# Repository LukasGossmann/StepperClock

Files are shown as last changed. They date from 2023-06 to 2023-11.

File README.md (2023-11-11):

<p align="center">
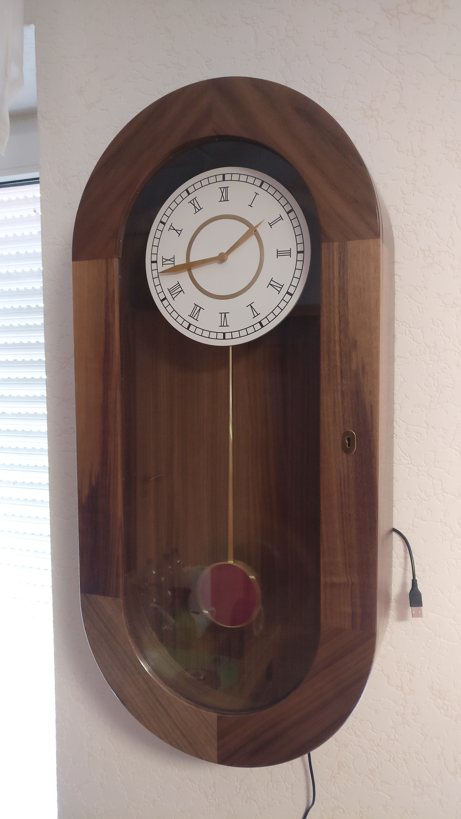
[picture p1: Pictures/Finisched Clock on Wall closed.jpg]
Front view of the clock with the door closed

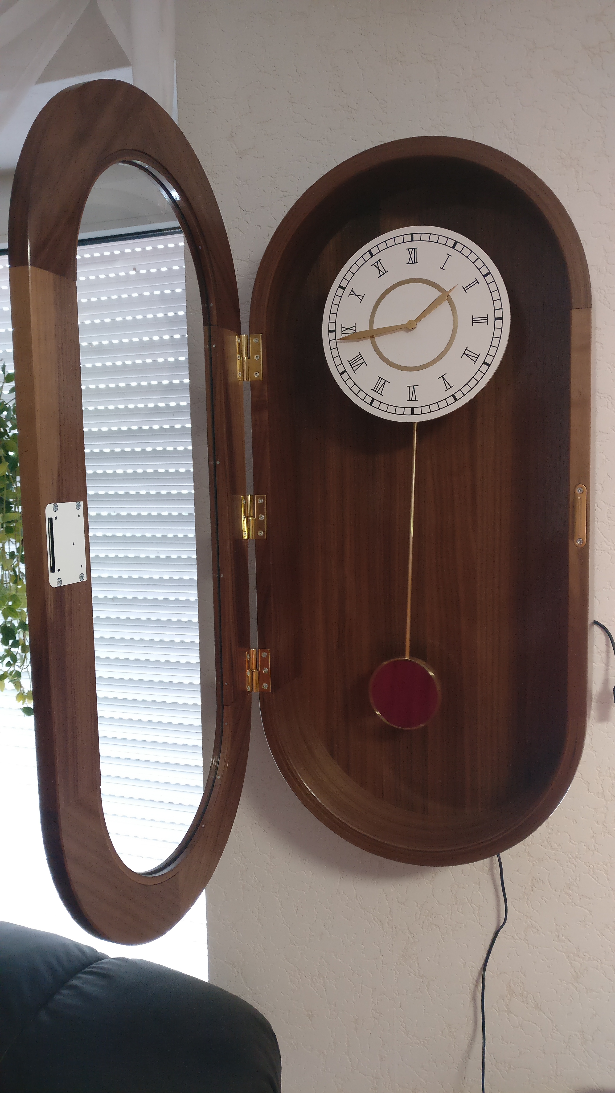
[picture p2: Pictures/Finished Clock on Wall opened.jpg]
Front view of the clock with the door opened

</p>

# The clockwork
The clock hands are moved by 2 Nema8 double shaft stepper motors (one hollow shaft and one normal one).  
To allow the clock to move its hands smoothly and nearly completely silently the stepper motors are driven using 2 Trinamic TMC2209 SilentStepStick modules configured for 256x microstepping. `200 full steps * 256 micro steps = 51200 steps per rev`  
The structural parts of the clockwork are CNC cut from 3mm Resopal and slotted together.  
Unfortunately i mostly forgot to take pictures of the build process and the finished clockwork before installing it so only the CAD drawings show how everything fits together.

<p align="center">
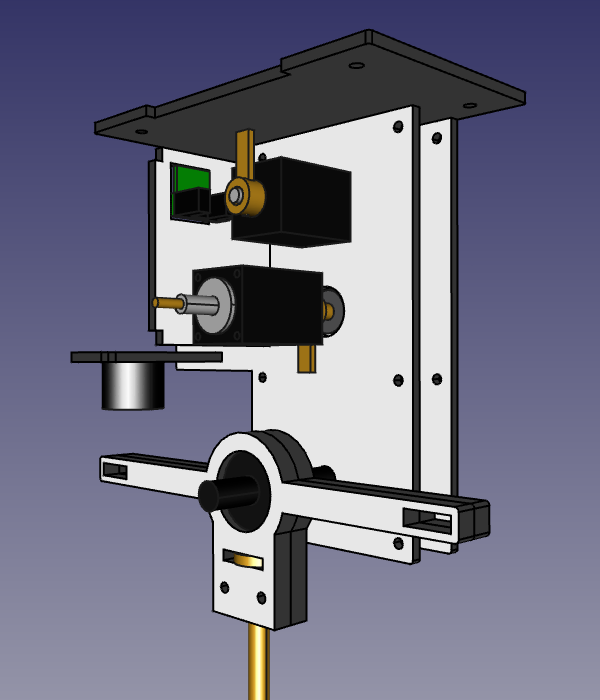
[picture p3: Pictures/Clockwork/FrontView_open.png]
Clockwork from the front with with front plate removed

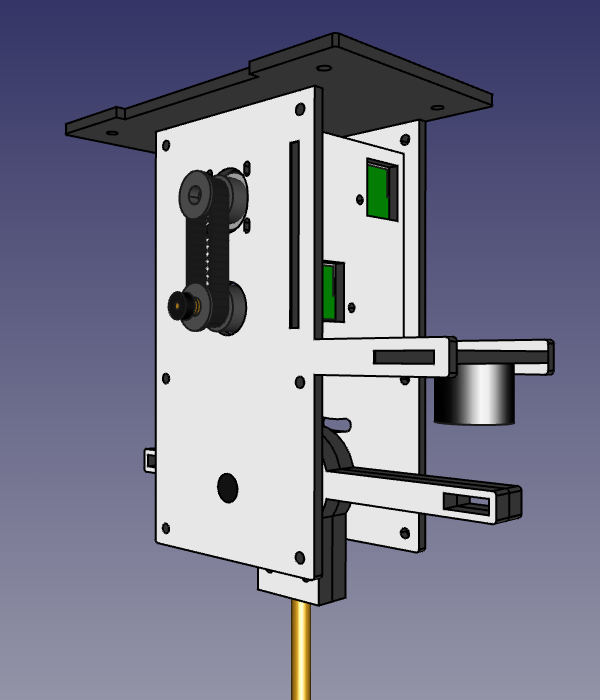
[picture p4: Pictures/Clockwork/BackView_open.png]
Clockwork from the back with with back plate removed

</p>

# The pendulum
The completed and polished pendulum

Its driven by a small electromagnet at the frequency that the pendulum would naturally swing at.  
`Pendulum length = 350mm, Frequency = 0.8425Hz`  
The brass ring was made using a small ring rolling / metal bending machine and soldered together at the seam.  
For additional rigidity the pendulum shaft goes through the ring and is soldered to it at both the top and bottom.  
Inside of the ring are 2 circular slices of purple heart wood with slots for the shaft to pass through.  
They are just press fit in place and can be removed with a suction cup in case the brass needs to be re-polished.  

# The bell mechanism
Originally the design of the clock included a 5 tone bell mechanism that used solenoids which hit against brass rods.  
This part of the design was later abandoned due to the bells not sounding that good.  
The new design of the clockwork no longer includes the bells.  
There is a few pictures of the old assembly in the pictures folder.

<br clear="right"/>

# The dial plate
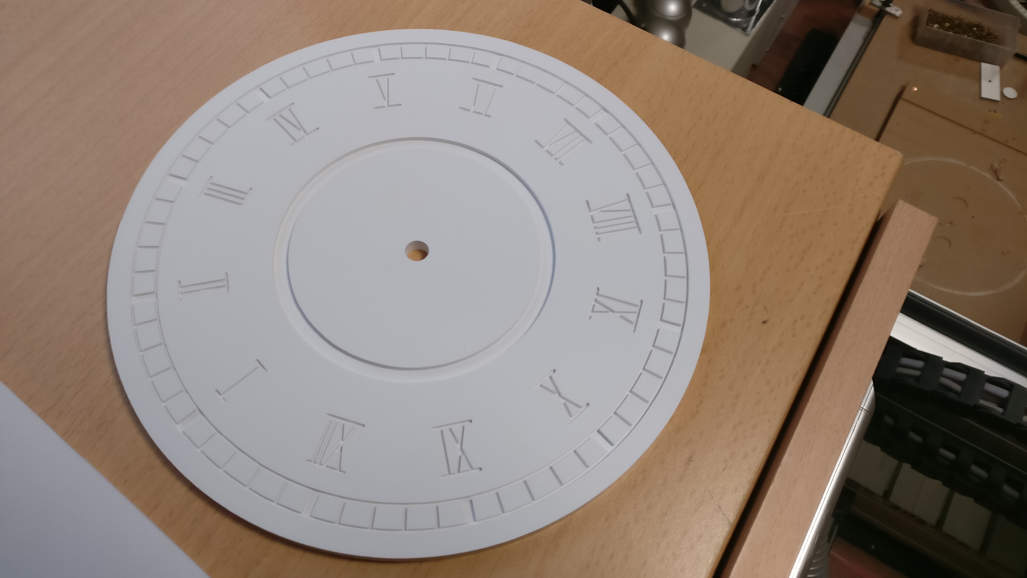
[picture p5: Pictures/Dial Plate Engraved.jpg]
The engraved dial plate without epoxy and the brass ring


Its made from Corian that has been engraved with a 1mm carbide endmill.  
The engraving was then filled with black epoxy and a brass ring.  
After that everything was sanded flush and polished.  

<br clear="left"/>

# The electronics
The brain of this clock is a Raspberry Pi Pico. In total 4 PWM units are used to control the clock. 2 PWM units are used to drive the hands.  
The first PWM unit drives the minute hand at `(200 full steps * 256 microstepping)/(60 seconds * 60 minutes) = 14.22222222222222222Hz` which is still within reach of the PWM unit at normal system clock speeds.  
However the hour hand needs a step pulse at just 1/12th of this frequency `1.18518518519Hz` which is way too low for the PWM units to reach.  
So instead of generating the hour pulse directly, the second PWM unit is configured to be driven by the output of first pwn unit (using an external jumper) and just divides the frequency by 12.  
  
The same idea is also used to drive the very low frequency PWM output for the pendulum.  
In that case a 10khz clock is divided down to the desired frequency and the pulse width is adjustable as well for different power supply voltages.  

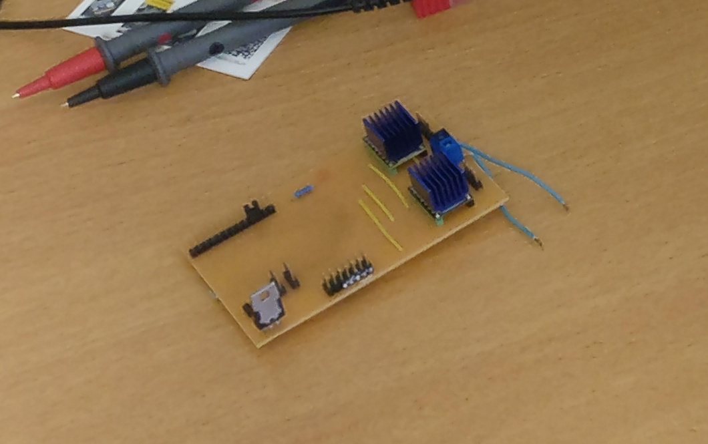
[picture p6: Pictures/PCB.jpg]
Older revision of the PCB


The time can be set through a text prompt via a USB serial terminal.  
When the time is set the clock hands automatically home, using 2 optical limit switches, and after that drive to the set time.  
At night the clock also goes into a power saving mode where the clock hands and the pendulum stop moving.  
When powering back up the clock hands home again and drive to the current time.  

There is unfortunately not very many pictures of the PCB itself because i again forgot to take pictures.  
I managed to find it in the background of some pictures of other projects though so i cropped out the unimportant bits (which is also why the quality of those pictures isn't great...)

<br clear="left"/>

# The lock
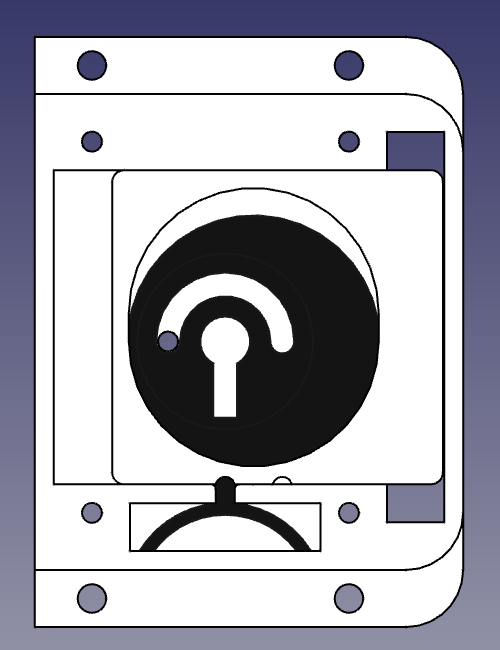
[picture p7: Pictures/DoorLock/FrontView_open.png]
Front view of the lock with the cover removed


The lock is custom designed for this clock. It can be used for all types of full overlay doors when the door is at least 12mm or so thick (the lock is just 9mm thick).  
Once installed the lock and latch plate don't take up any space inside whatever enclosure they are used in.  
The latch of the lock is moved using an eccentric cam whose center of rotation is the key shaft.  
A small plastic spring is used to give some audible and haptic feedback on when the key has been rotated far enough.  

<br clear="right"/>

# The case
It was actually build as my journeyman's piece for the apprenticeship as a carpenter I completed in August of 2023.  
The case consists of 2 big half circles that were made by gluing ten 2mm pieces of veneer together while clamped to a mold.  
After the glue dries the pieces keep the shape and are actually surprisingly stiff.  
All the relevant documents that have to be submitted (Drawings, Concept, etc.) to get the project approved are also available in this repository for anyone interested.  
That is also why the repository contains a mix of German and English.  
To document the build process and show how certain things were made (in case anyone wants to replicate the project) I took a lot of pictures while building it.  
The clock was on display at the Forum Alstertal in Hamburg, Germany at the yearly exhibition of carpentry journeyman's pieces:  
`30th of June to the 05th July 2023`  
[Link to the event](https://www.forum-alstertal.de/news_veranstaltungen_detail_394.html)

# Awards
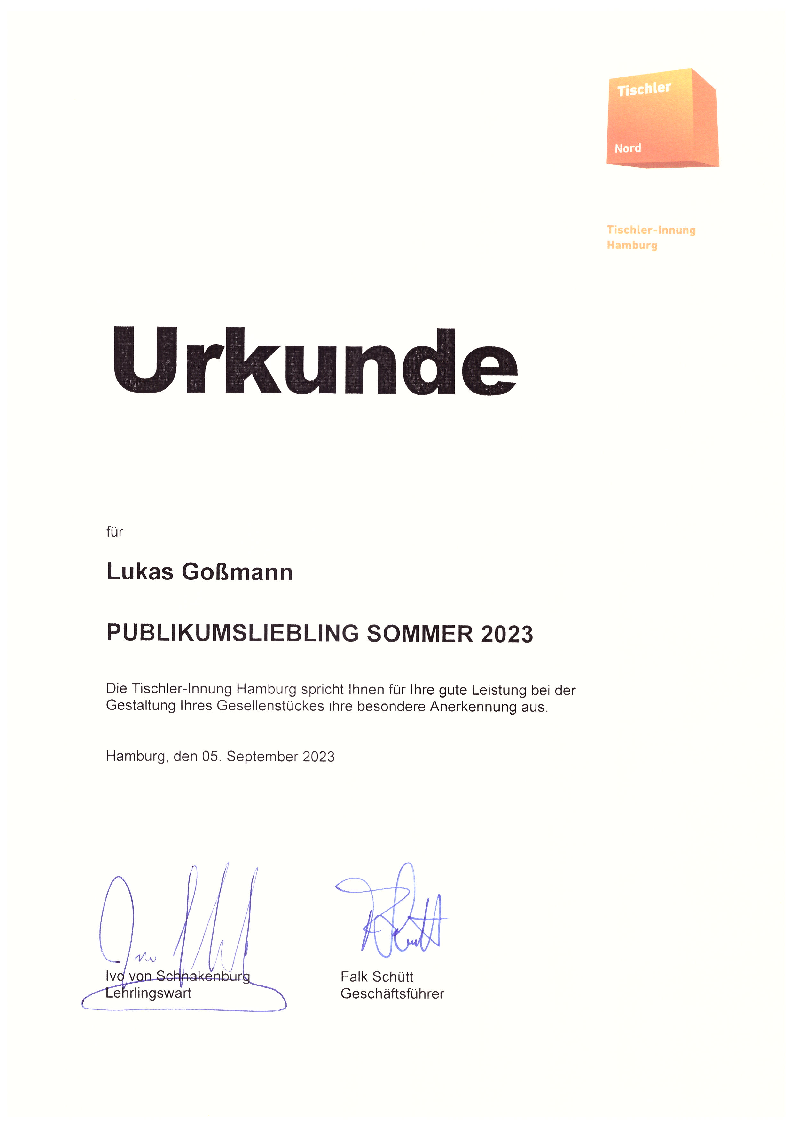
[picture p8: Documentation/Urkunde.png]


During the exhibition the residents living at the Forum Alstertal get the opportunity to vote on their favorite piece.
This year my clock won the audience award.

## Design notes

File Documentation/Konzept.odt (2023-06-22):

Wanduhr mit elektrischem Uhrwerk und Pendel

Als Gesellenstück soll ein abschließbares Gehäuse für ein bereits bestehendes selbst entwickeltes Uhrwerk, sowie das Pendel für dieses gebaut werden. Da das Pendel nur dekorativ ist, ist dessen Länge mehr oder weniger frei wählbar. Um zumindest nahe an die normale Pendelfrequenz von 1Hz zu kommen und trotzdem ein optisch ansprechendes Verhältnis von Pendellänge und Ziffernblattdurchmesser zu erreichen, wurde eine Länge von 350mm ab dem Drehpunkt (400mm von Mitte Ziffernblatt, Ziffernblatt 200mm Durchmesser) gewählt. Das Pendelgewicht soll aus einem Messingring mit Holzfüllung gefertigt werden und wird an einer Messingstange aufgehängt. Eine entsprechende Aufnahme für die Messingstange ist am Uhrwerk vorhanden. Die Maße die sich aus den genannten Anforderungen für den Korpus ergeben, entsprechen weniger denen einer Standuhr, sondern eher denen einer Wanduhr. Da das Uhrwerk einen festen Stromanschluss benötigt, muss die Rückwand des Gehäuses etwas weiter in den Korpus zurück springen, sodass zwischen Rückwand und der Wand an der die Uhr hängt etwa 10mm Platz sind. Um das Uhrwerk, das Ziffernblatt und das Pendel vor Staub und Berührungen zu schützen soll ein komplett geschlossener Korpus mit Glasfüllung in der Tür gebaut werden. Wie dies bei Uhren dieser Art häufiger der Fall ist, soll die Tür eine einfach Aufschlagende sein. Da die Tür jedoch abschließbar sein soll, um z.B. neugierige Blicke auf der Gesellenstücksausstellung vom empfindlichen Uhrwerk fernzuhalten, ergibt sich hier eine weitere Herausforderung, die jedoch mit einem selbst entwickelten Beschlag gelöst werden konnte. Das Schloss wird in die Innenseite der Tür eingelassen und greift in ein Schließblech das aus der Korpusseite heraussteht. Aus den oben genannten Anforderungen ergibt sich nun das Bild eines relativ klassischen Uhrengehäuses aus mittel bis dunklem Holz mit vielen Verzierungen und Messing Elementen. Da die vielen Verzierungen jedoch nicht unbedingt Zeitgemäß aussehen, wurde stattdessen eine eher schlichte / minimalistische Optik gewählt. Der dunklere Holzton sowie die Messing Elemente werden jedoch im Design aufgegriffen. Um die runde Form des Ziffernblattes zu betonen und eine gewisse vertikale Symmetrie mit dem runden Pendelgewicht zu haben, soll der Korpus oben und unten rund sein. Dies wird durch die Formverleimung mehrerer Furnierlagen erreicht. Um den Rundbogen der Tür zu fertigen, ohne das dieser an den Scheitelpunkten des Kreises durch „kurzes Holz“ instabil wird, wurde ein um 45° gekippter Faserverlauf gewählt.

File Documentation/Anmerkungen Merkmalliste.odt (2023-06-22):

Anmerkungen zu Merkmalliste

Statische Hülle: Korpus aus Vollholz mit furnierter Sperrholz Rückwand und formverleimten Rundungen

Einfügen eines oder mehrerer beweglicher Teile: Aufschlagende Drehtür

Klassische Vollholzverbindungen: Verwendung von Dominos um die geraden Korpusseiten mit den formverleimten Rundungen zu verbinden

Furnierte Flächen oder Vollholzflächen: selbst Furnierte Sperrholz Rückwand, gerade Korpus Seiten und Tür

Eingestemmte Bänder und Schlösser: 3x Möbelband Kröpfung A und selbst entwickeltes Möbelschloss mit Schließblech

Geschweifte Teile: Rundbogen Tür die mit Schablone gefräst wird

Geschweifte Flächen: Formverleimung der runden Korpusflächen

Verarbeitung von Kunststoffen und Metallen: Selbst entwickelter Beschlag aus Resopal und 3D gedrucktem PLA, Schließblech aus Messing, gewalzter Messingring und Messingstange für Pendel, verlöten der Messing Einzelteile des Schließblechs und des Pendels

Verwendung und Einbau besonderer Halbzeuge: zuvor selbst entwickeltes Elektrisches Uhrwerk

Selbst entwickelte Beschläge und Mechanismen: selbst entwickeltes Schloss und Schließblech für Aufschlagende Türen

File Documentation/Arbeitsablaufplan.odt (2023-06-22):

Arbeitsablaufplan

Fertigung der Rundbögen (2 Stück)

Nr. | Arbeitsschritte | Werkzeuge, Maschinen, Vorrichtungen, Bemerkungen | Kalk. Ferti-gungszeit (min) inkl. Rüstzeit
1 | Bohle auftrennen | Handkreissäge / Kettensäge | 15
2 | Bohle besäumen und Kanteln schneiden | Formatkreissäge, Kreissägeblatt Langholz, Fritz und Franz | 15
3 | Kanteln abrichten und Winkelkante hobeln | Abrichthobelmaschiene | 10
4 | Kanteln aushobeln | Dickenhobelmaschiene | 10
5 | Kanteln zu Sägefurnier auftrennen | Formatkkreissäge, Kreissägeblatt Langholz, Spannvorrichtung Kanteln Dicke nach sägen ca. 3 bis 4mm | 40
6 | Furnier auf Fertigdicke aushobeln | Dickenhobelmaschiene, Dicke nach Hobeln: 2mm, Für innere und äußere Furniere +0.2mm wegen schleifen der Oberflächen | 40
7 | Schleifen der Furniere für die Innenseite der Rundung | Exzenterschleifer, Staubsauger, Zulagen, Zwingen, Doppelseitiges Klebeband | 10
8 | Verleimvorrichtung vorbereiten | Verleimvorrichtung, Zwingen, Zulagen, Leim, Wasser und Lappen | 30
9 | Rundbögen verleimen | Verleimvorrichtung, Zwingen, Zulagen, Leim, Wasser und Lappen | 60
10 | Rundbögen mit Vorrichtung auf Fertigmaß zuschneiden | Verleimvorrichtung, Formatkreissäge, Kreissägeblatt Langholz und Querholz | 60
11 | Domino Fräsungen zur Verbindung mit den geraden Seitenteilen | Verleimvorrichtung, Domino Fräse, Staubsauger, Zwingen Dominofräse an die Verleimvorrichtung anlegen um gerade in die Rundbögen zu fräsen | 15
12 | Schleifen der Rundbögen | Extenterschleifer, Staubsauger, Handschleifpapier | 40
| | Gesamt: | 335 min (5:35)

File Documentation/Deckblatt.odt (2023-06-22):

Wanduhr mit elektrischem Uhrwerk und Pendel

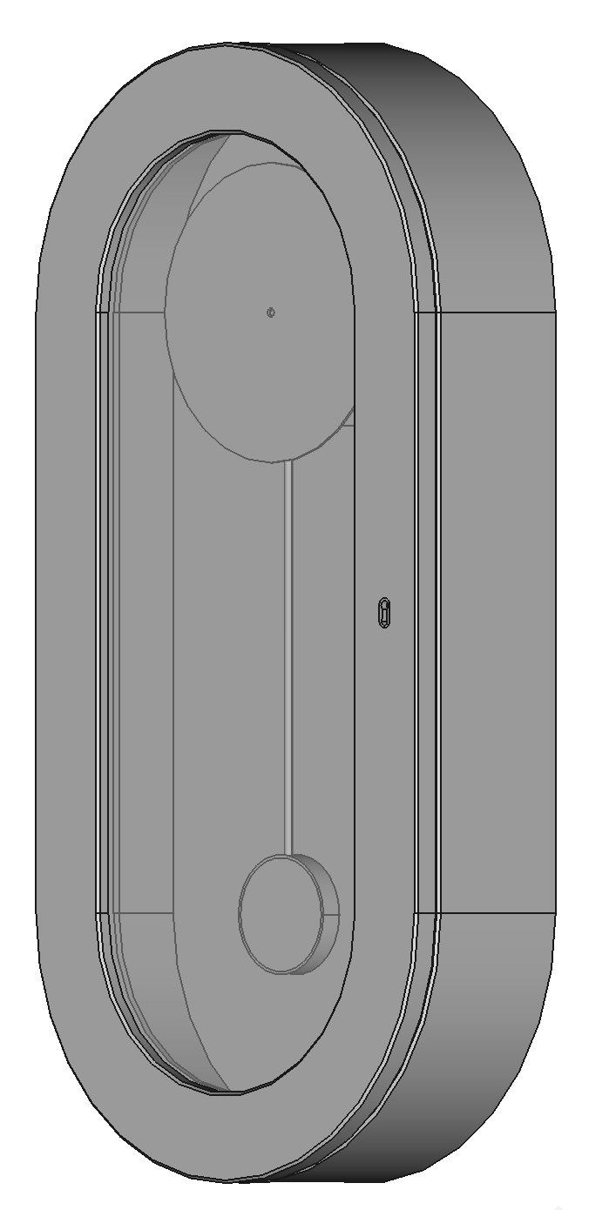
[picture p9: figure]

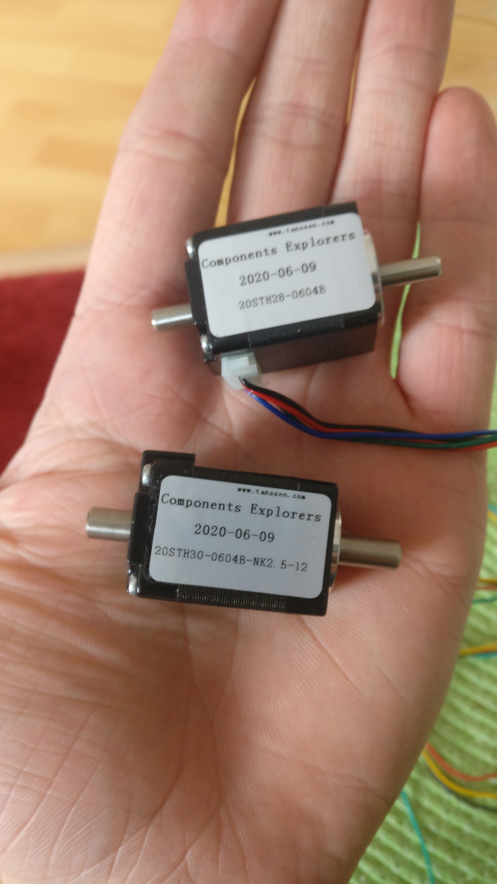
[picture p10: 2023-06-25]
Pictures/Stepper Motors.jpg

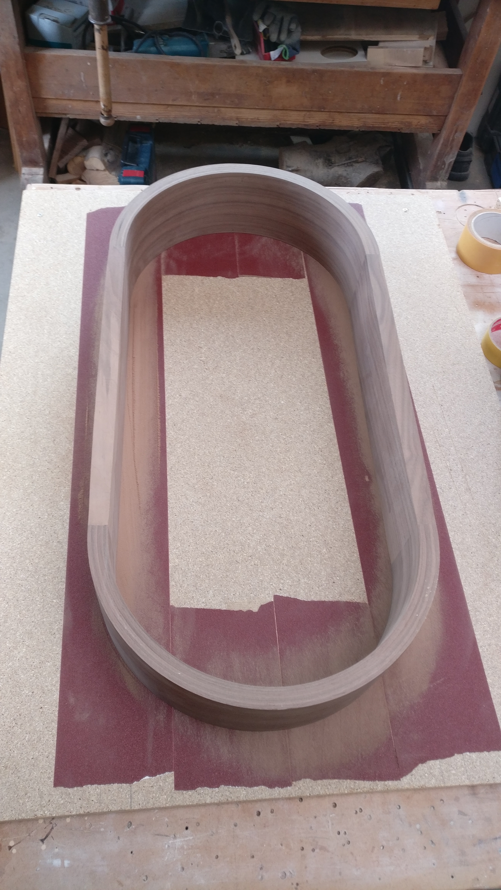
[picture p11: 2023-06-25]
Pictures/Sanding case flush.jpg

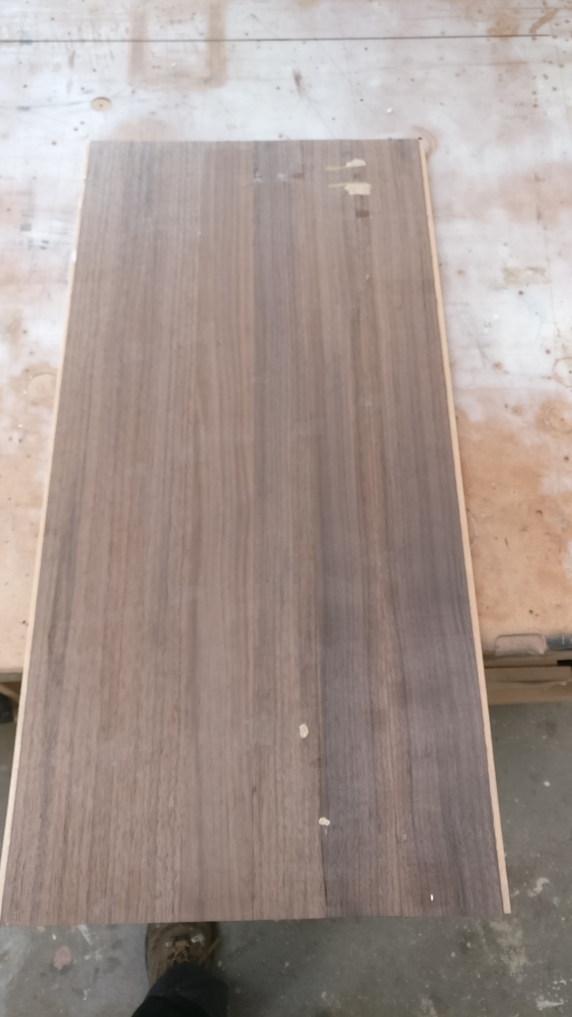
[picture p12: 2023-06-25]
Pictures/Backplate Veneer Front.jpg

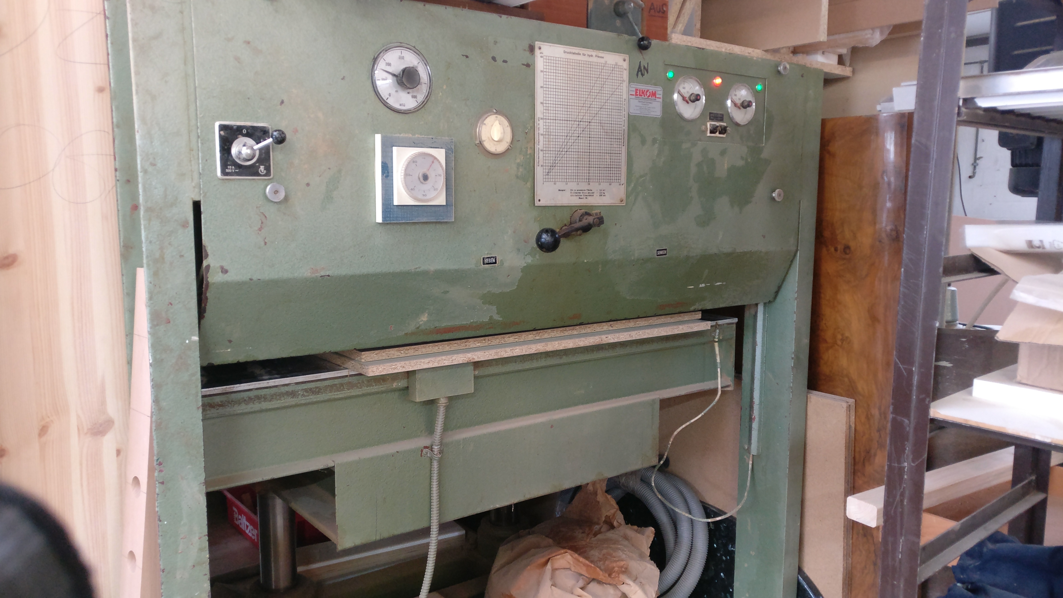
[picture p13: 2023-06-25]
Pictures/Veneer Press in Action.jpg

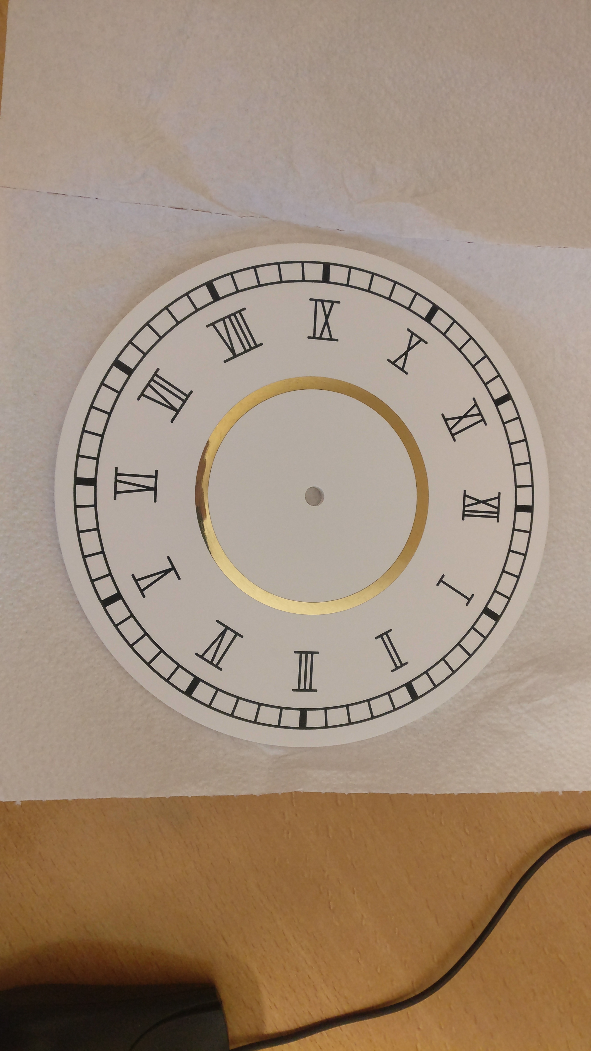
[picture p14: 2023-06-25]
Pictures/Dial Plate Done.jpg

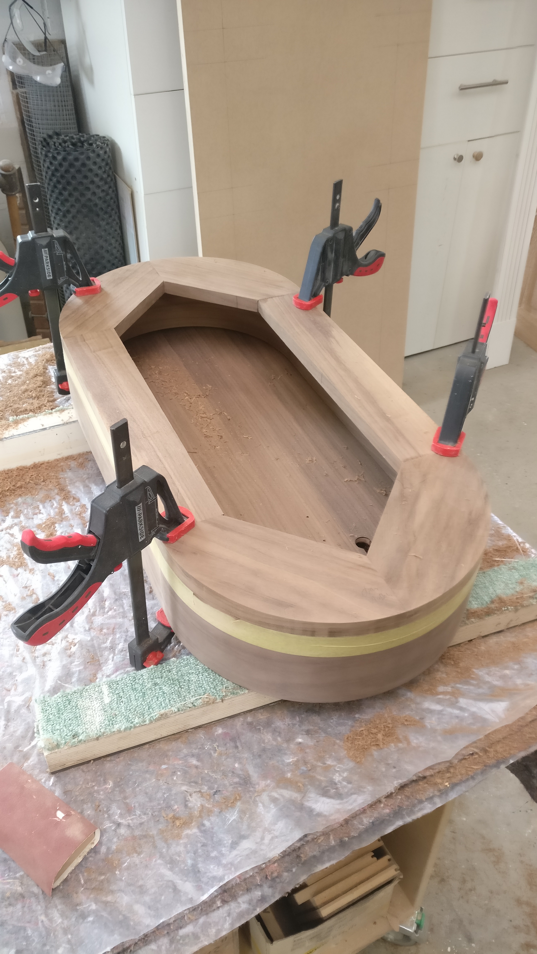
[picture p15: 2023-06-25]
Pictures/Flush trimming Door.jpg

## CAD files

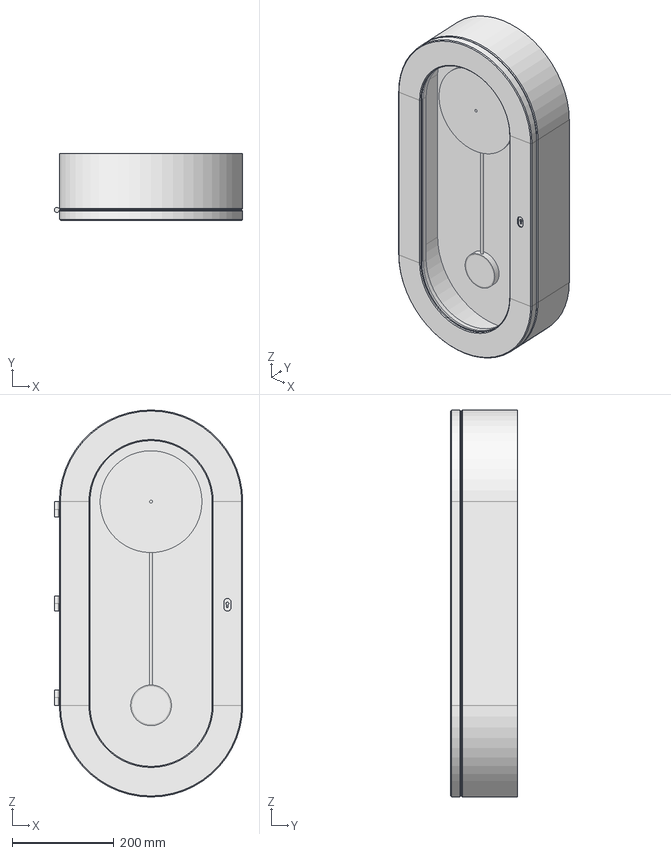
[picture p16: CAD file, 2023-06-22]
FreeCAD/Case/Case.FCStd
370.0 x 131.0 x 760.0 mm
FrontPart
BackPart
Clockwork
Glass
HangingPinLeft
HangingPinRight
HangerLockLeft
HangerLockRight

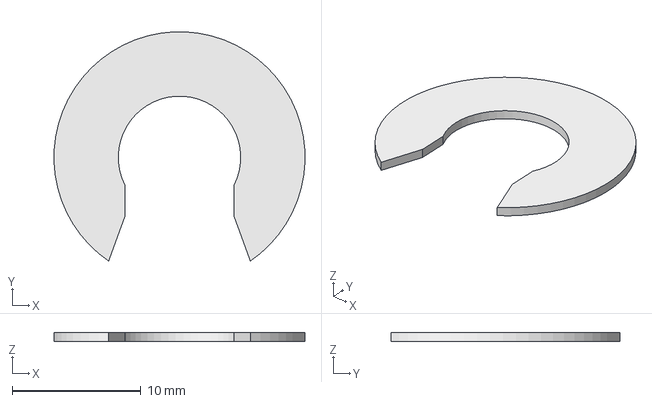
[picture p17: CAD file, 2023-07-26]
FreeCAD/Clip.FCStd
19.5 x 17.8 x 0.7 mm

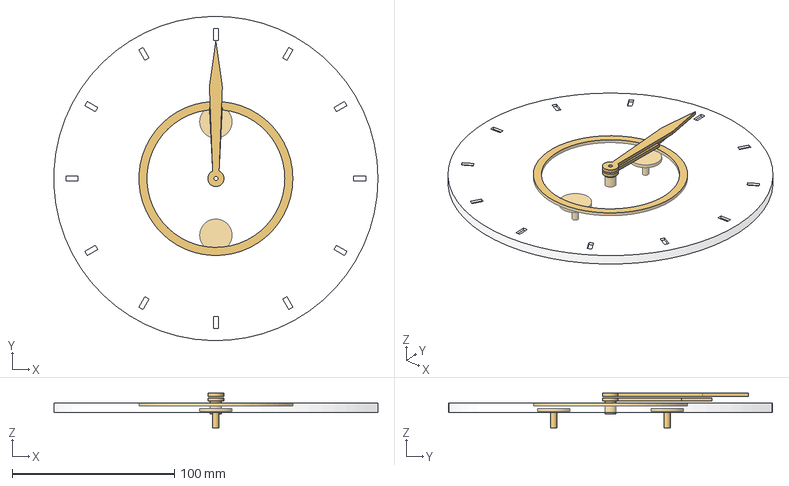
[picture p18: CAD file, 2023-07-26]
FreeCAD/Clockface/ClockFace.FCStd
199.9 x 199.9 x 21.5 mm
HourHand
MinuteHand
DialPlateMountTop
DialPlate
HourHandClip
DialPlateMountBottom
DialPlateBrassInlay

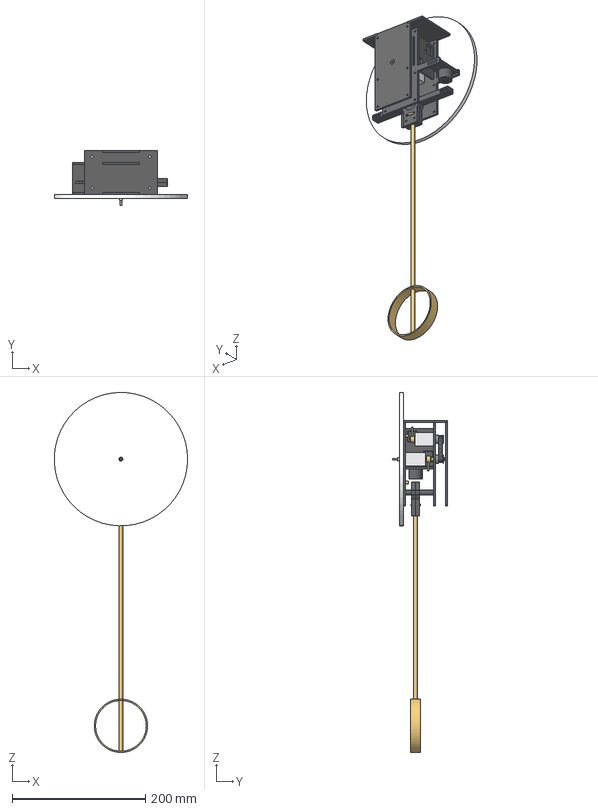
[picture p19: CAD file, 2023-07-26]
FreeCAD/Clockwork/Clock.FCStd
199.8 x 83.0 x 539.9 mm
FrontPlate
MiddlePlate
BackPlate
LimitSwitchMountPlate
PcbMountPlate
ElectromagnetMountPlate
PendulumClampBack
PendulumBearingShaft
PendelumBearing
PendulumClampFront
Pendulum001
DialPlatePlaceholder
DialPlateMountBottom
DialPlateMountTop
Electromagnet
HollowDoubleShaftStepper
DoubleShaftStepper
MinuteHomeSwitch
HourHomeSwitch
TimingPulleyHour
TimingPulleyMinute
LimitSwitchPinHour
LimitSwitchPinMinute
MinuteShaftBearing
MinuteShaft
GT2Belt

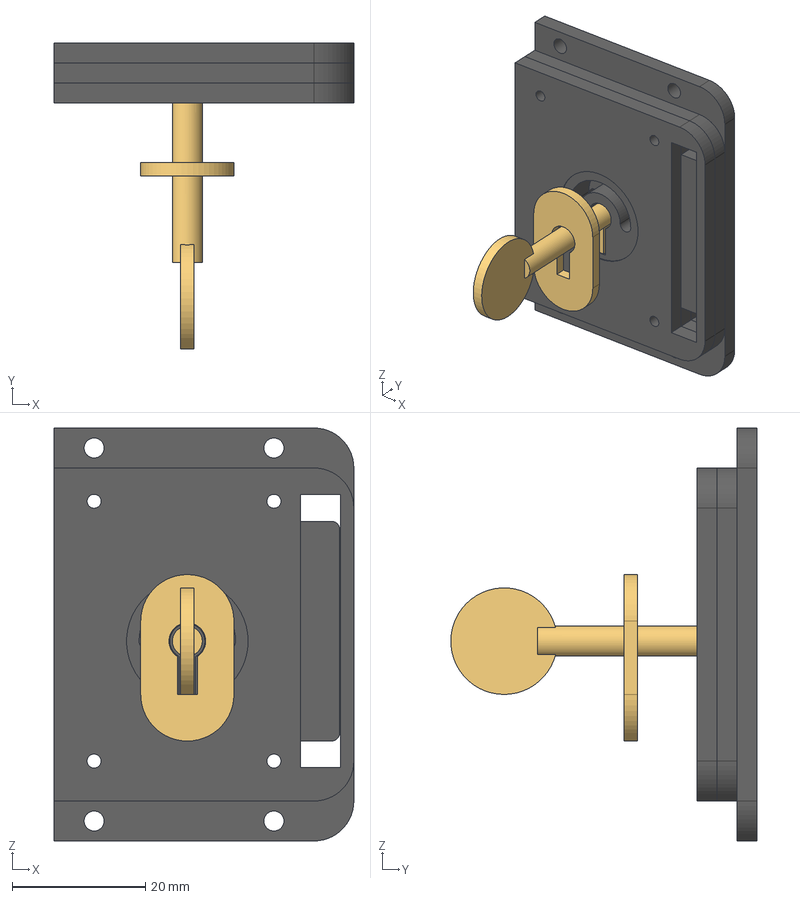
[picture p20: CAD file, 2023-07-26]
FreeCAD/DoorLock/DoorLock.FCStd
45.0 x 46.0 x 62.0 mm
KeyholeInsert
Slider
Spring
Spacer
FrontPlate
BackPlate
KeyHole
Key

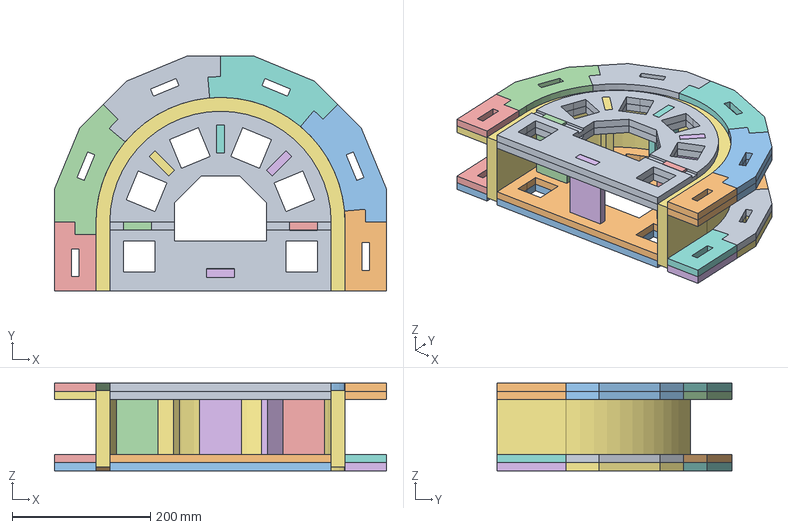
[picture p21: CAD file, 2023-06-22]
FreeCAD/Fixtures/BendingFixture.FCStd
480.0 x 340.0 x 127.0 mm
InnerTemplate
OuterTemplate1
OuterTemplate2
OuterTemplate5
OuterTemplate6
VerticalSpacer
FinishedPart
OuterTemplate3
OuterTemplate4
OuterTemplate007
OuterTemplate008
OuterTemplate009
OuterTemplate010
OuterTemplate011
OuterTemplate012
OuterTemplate013
OuterTemplate014
OuterTemplate015
OuterTemplate016
OuterTemplate017
OuterTemplate018
OuterTemplate019
OuterTemplate020
OuterTemplate021
OuterTemplate022
OuterTemplate023
OuterTemplate024
VerticalSpacer001
VerticalSpacer002
VerticalSpacer003
VerticalSpacer004
VerticalSpacer005
InnerTemplate001
InnerTemplate002
InnerTemplate003

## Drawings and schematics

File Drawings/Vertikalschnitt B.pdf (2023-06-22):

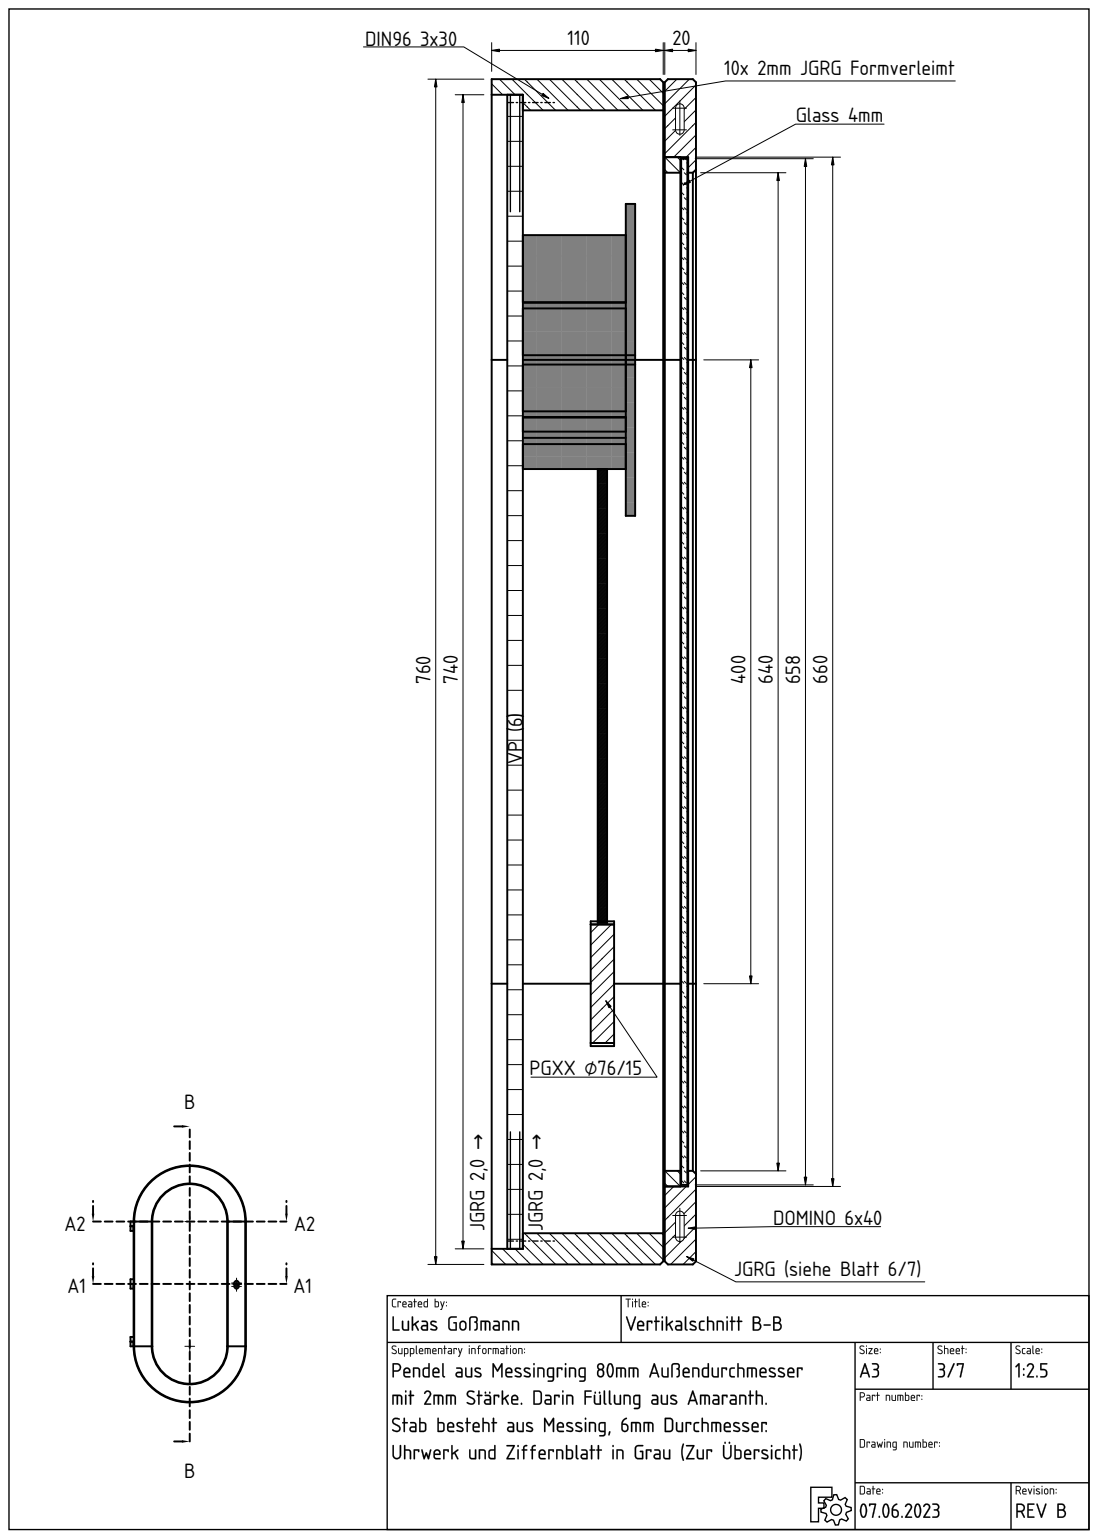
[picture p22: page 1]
PGXX ⌀76/15; 10x 2mm JGRG Formverleimt; Glass 4mm; DIN96 3x30

DOMINO 6x40
JGRG (siehe Blatt 6/7)

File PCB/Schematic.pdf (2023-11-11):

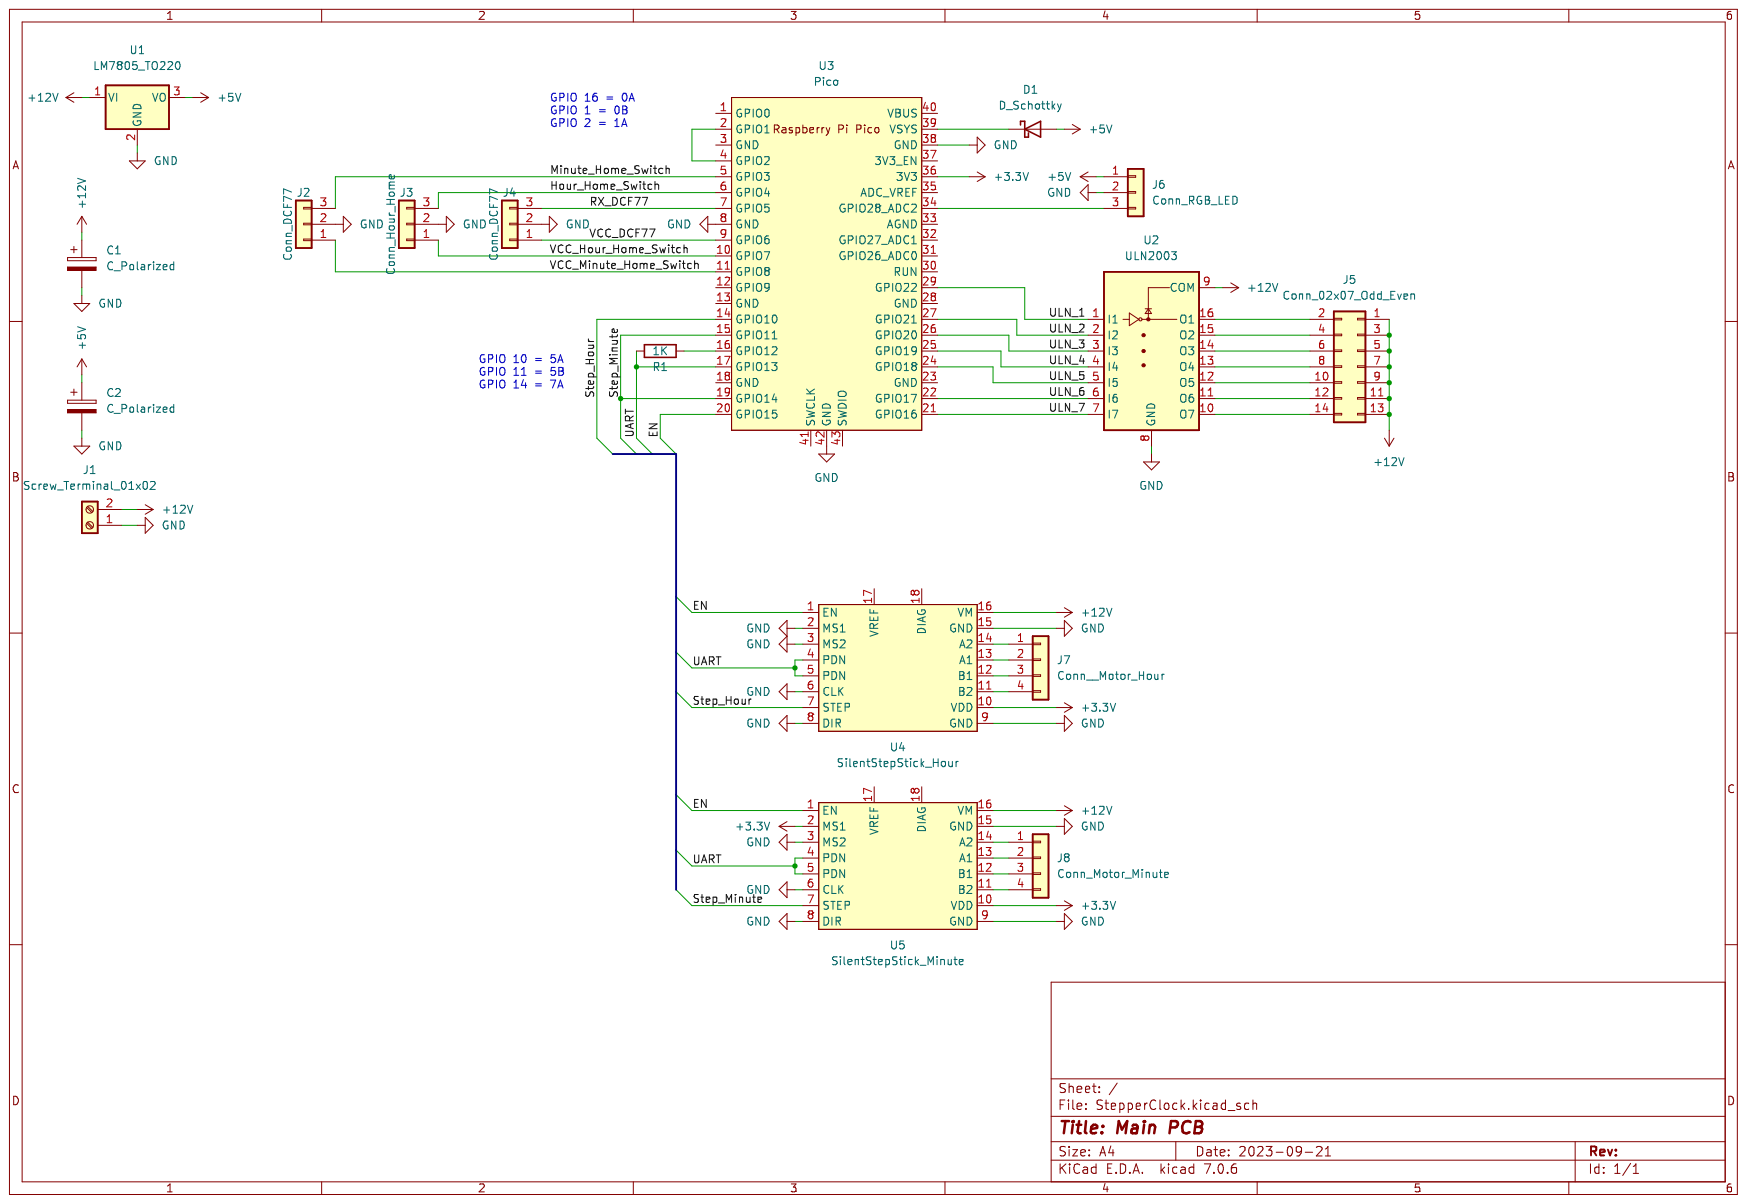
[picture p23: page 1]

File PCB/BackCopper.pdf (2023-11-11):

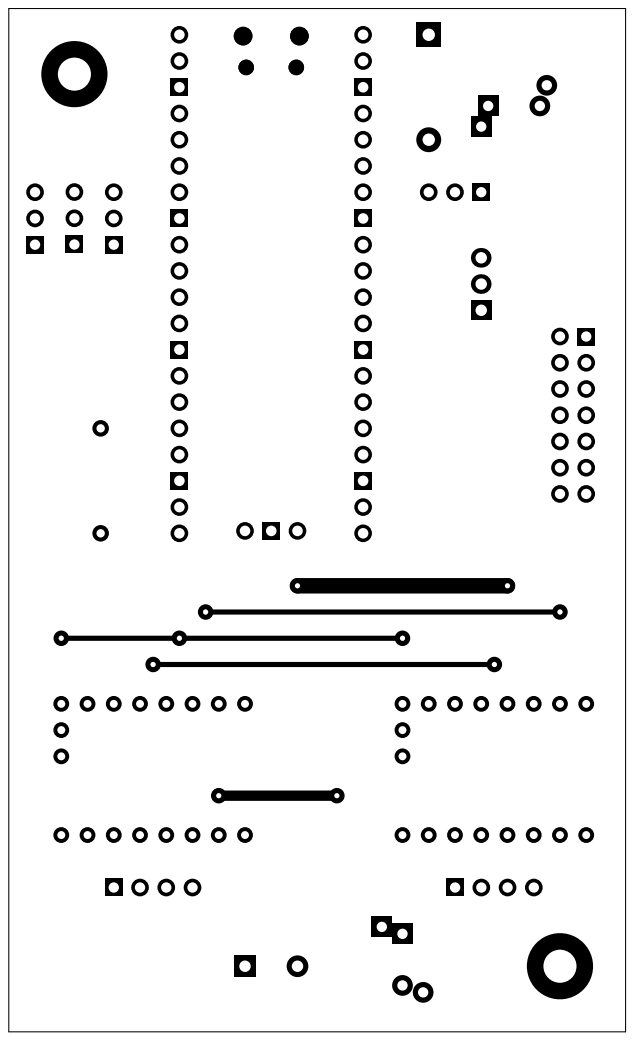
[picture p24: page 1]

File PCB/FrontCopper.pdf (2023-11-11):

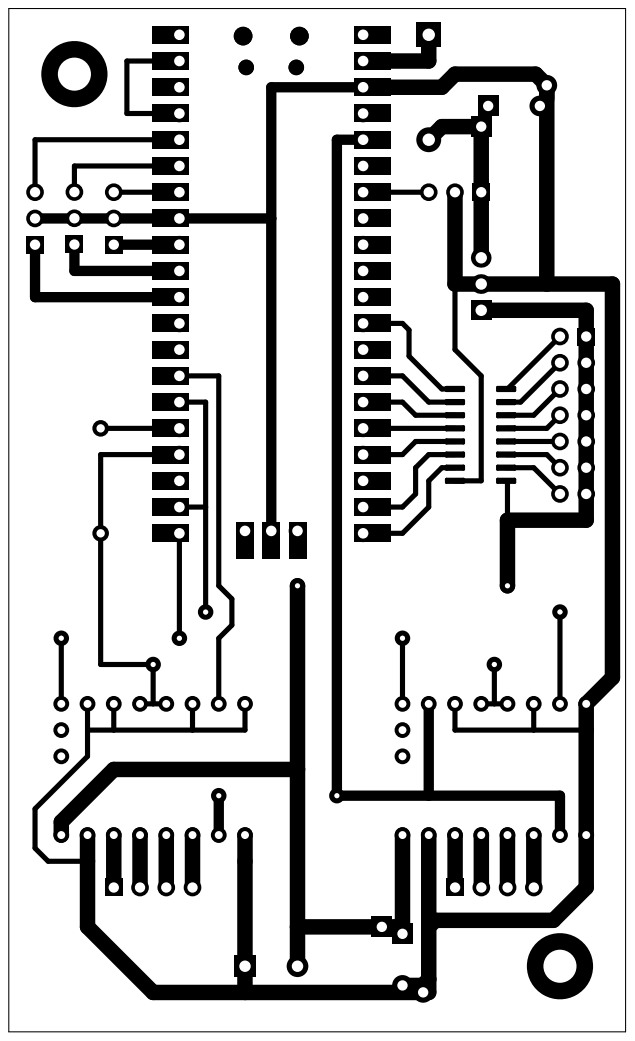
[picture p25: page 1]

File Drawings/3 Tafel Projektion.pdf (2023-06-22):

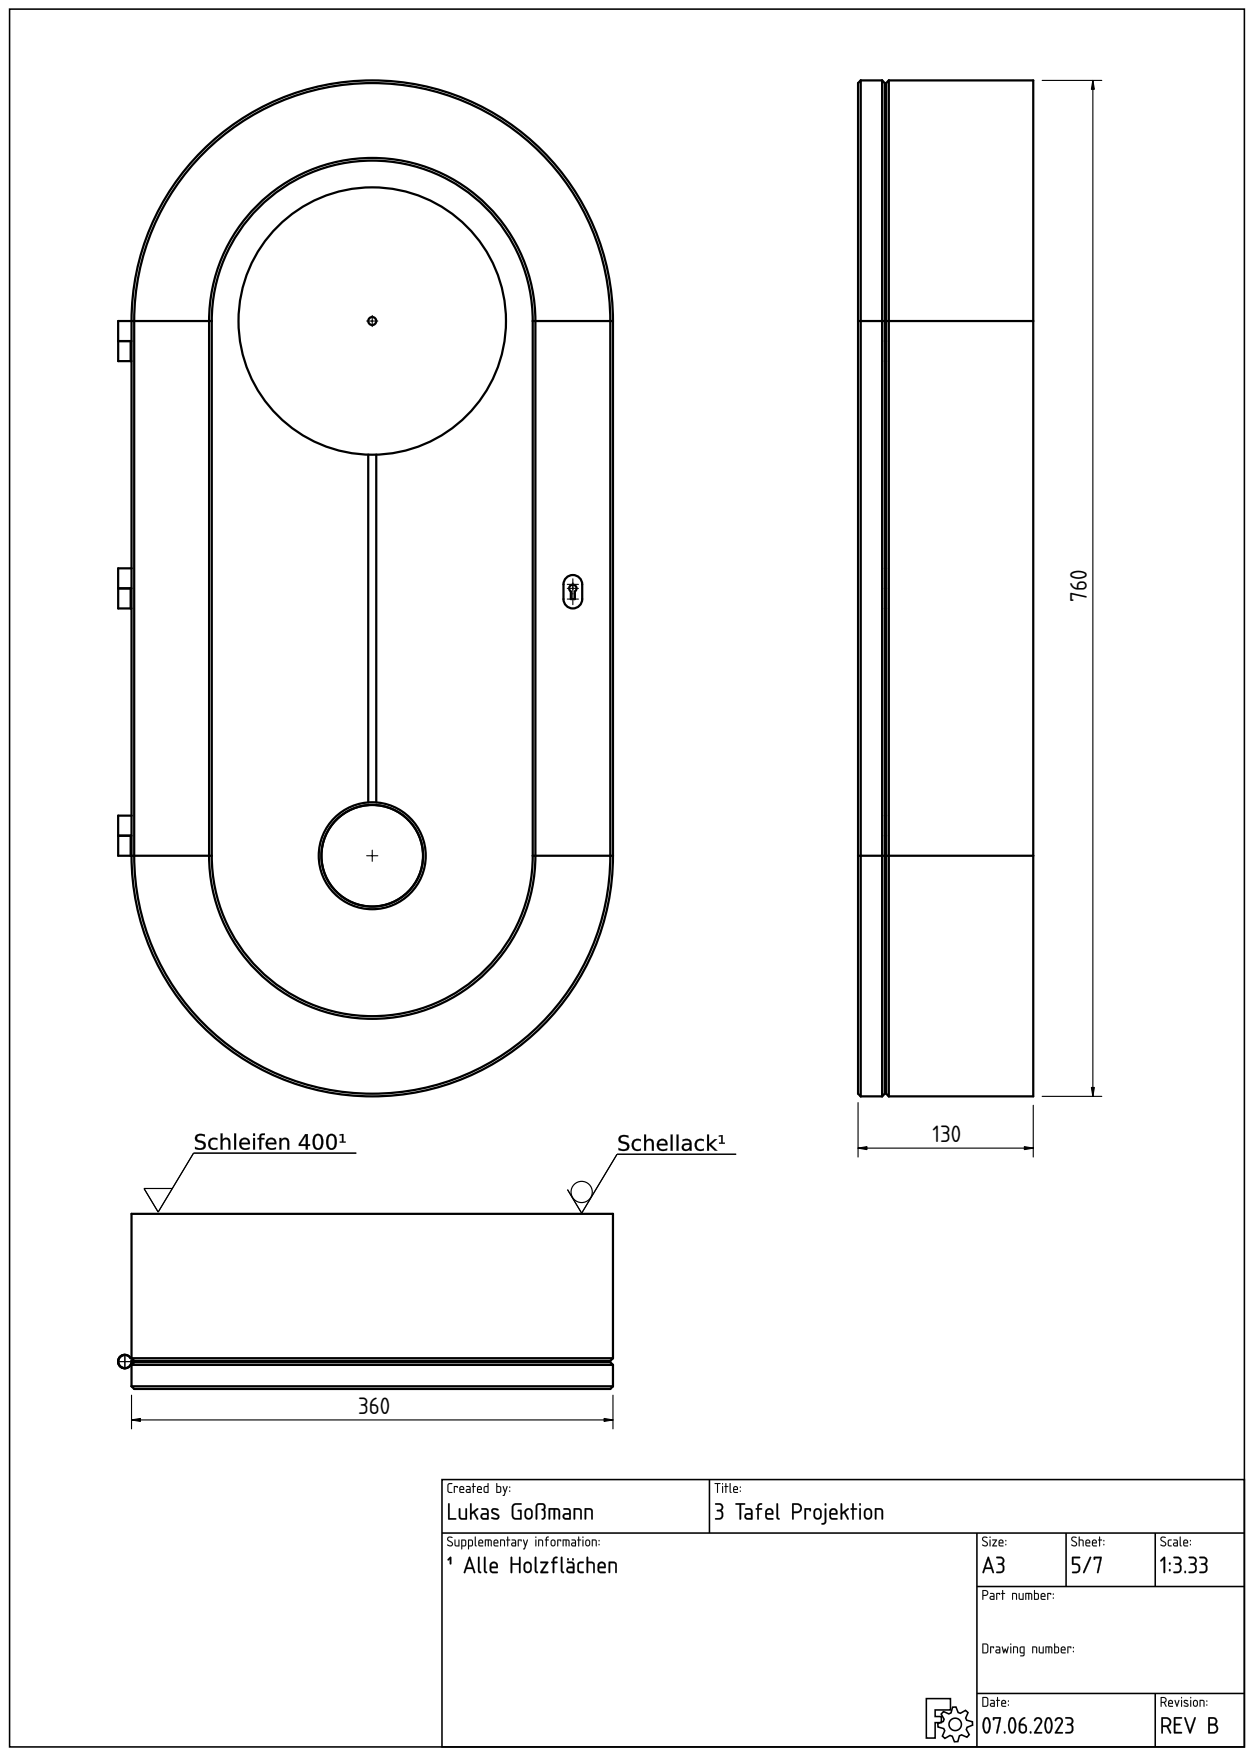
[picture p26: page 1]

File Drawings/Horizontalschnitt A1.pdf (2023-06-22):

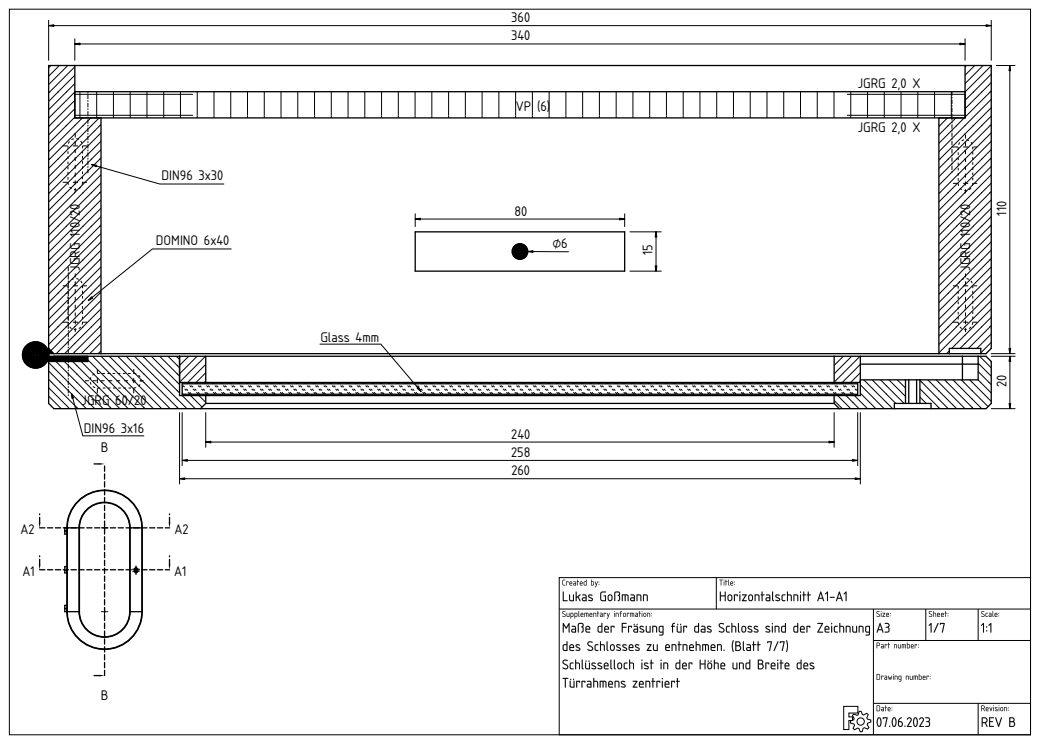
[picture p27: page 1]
JGRG 110/20; JGRG 110/20 JG; Gla; DIN; MIN

V | | X JGRG 2,0 X

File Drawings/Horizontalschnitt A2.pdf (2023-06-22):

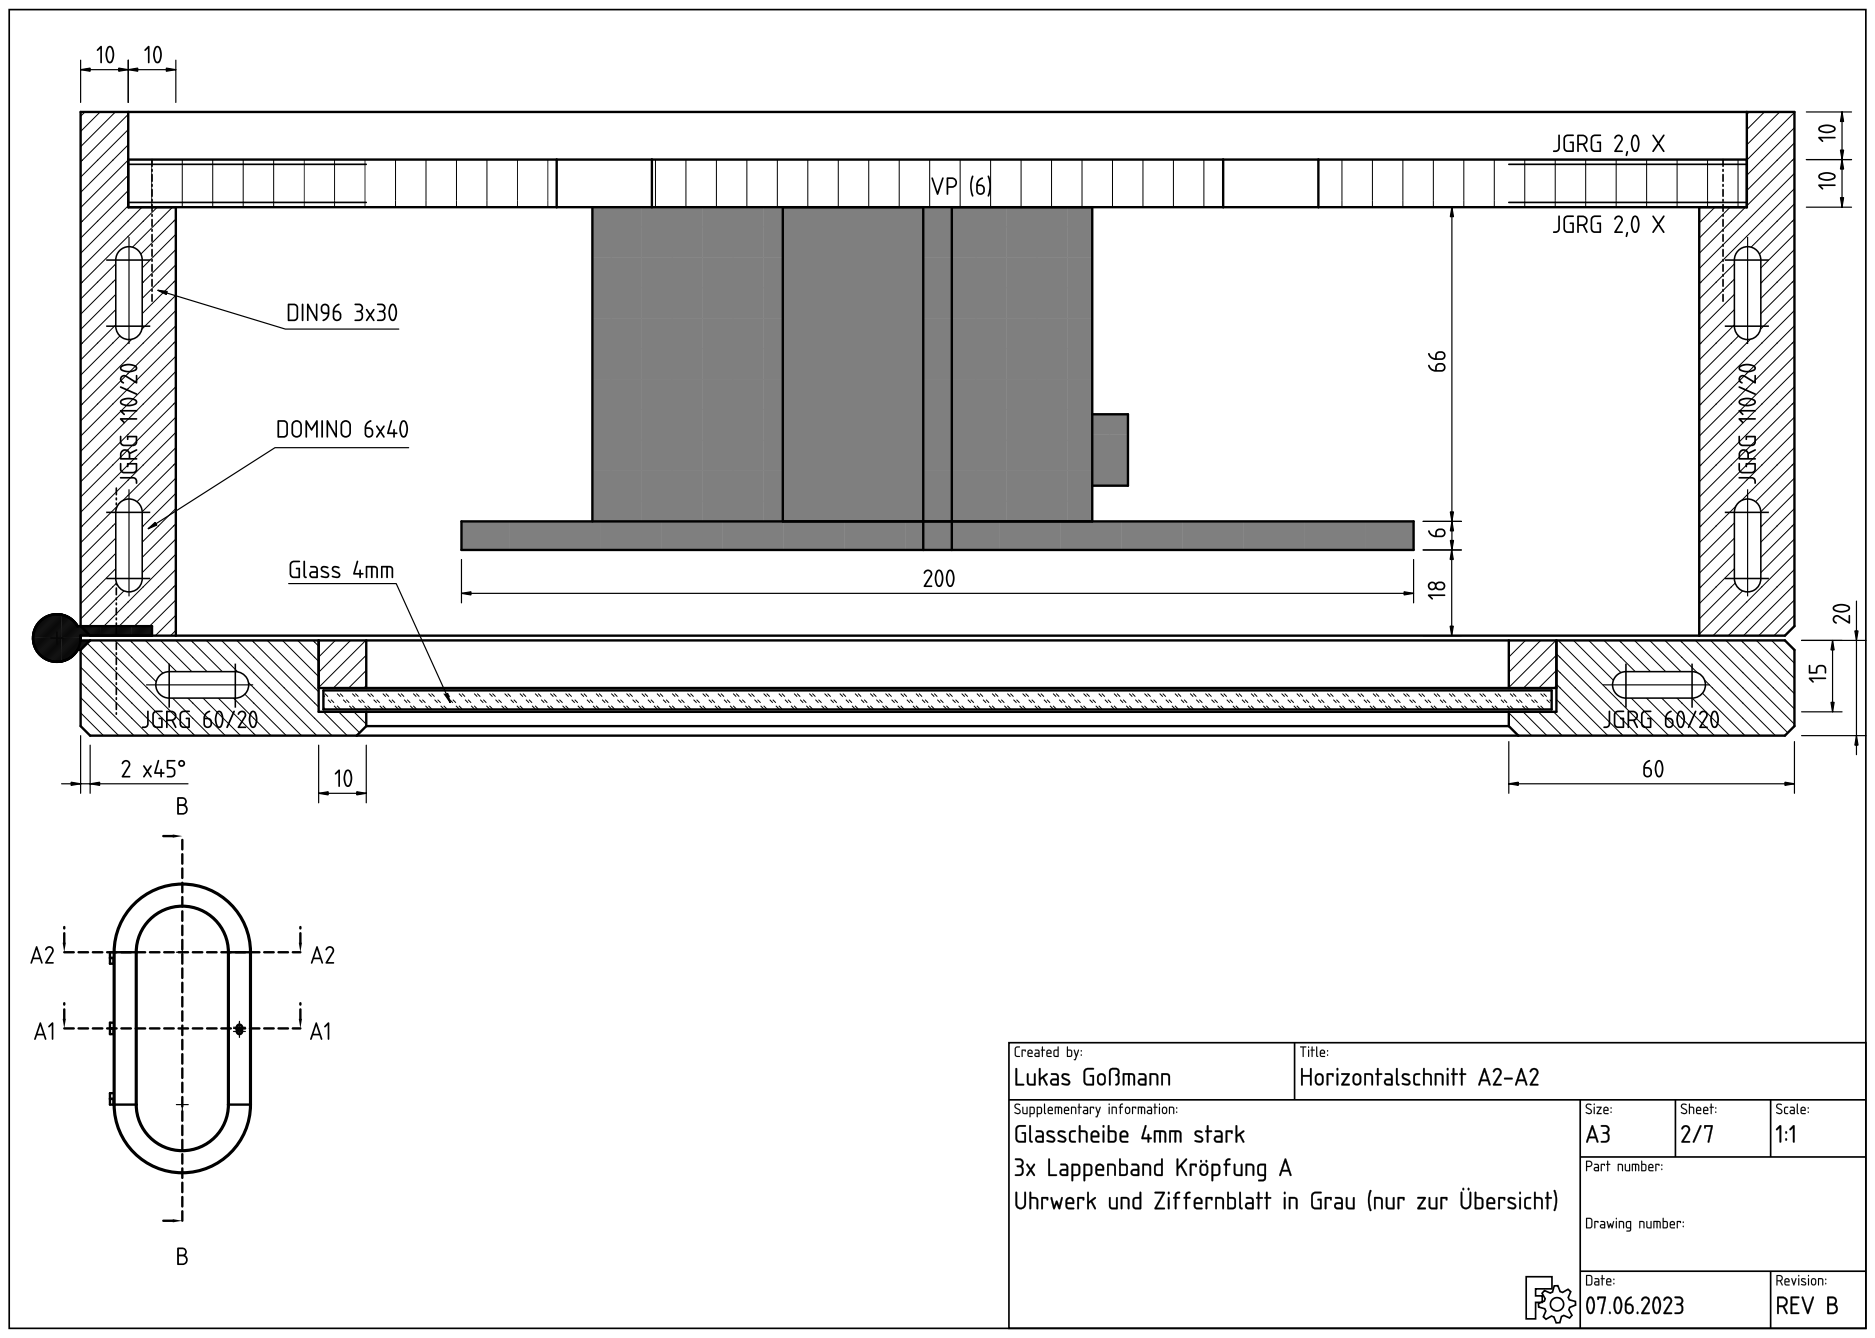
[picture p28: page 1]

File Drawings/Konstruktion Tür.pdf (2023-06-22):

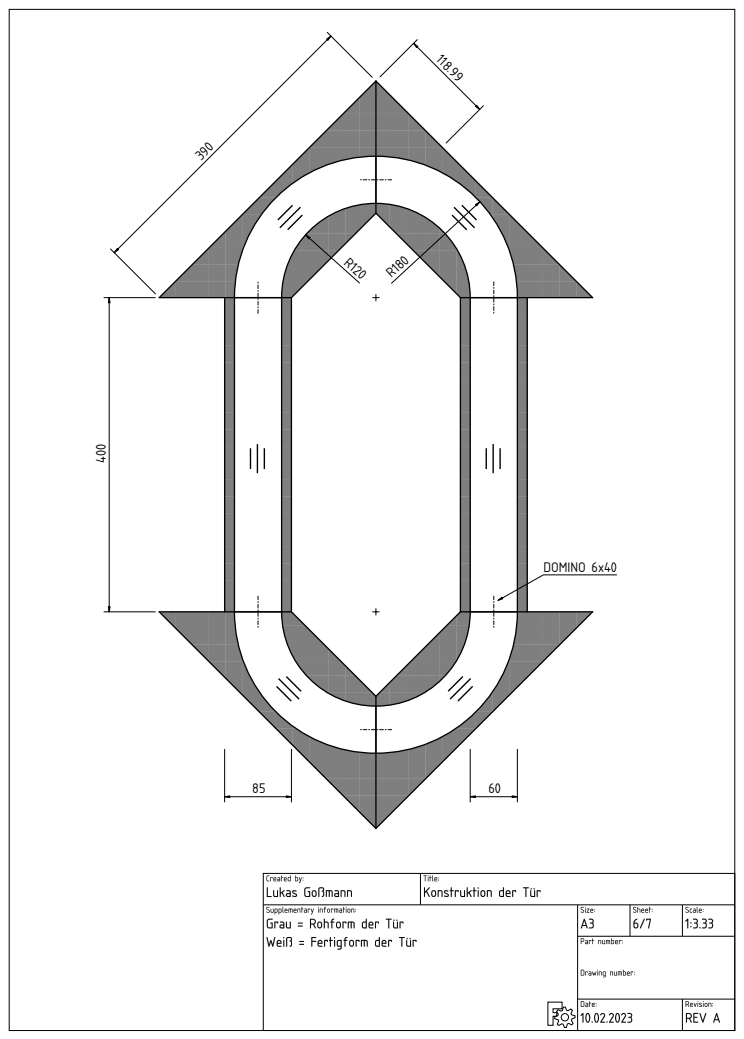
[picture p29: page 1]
DOMINO 6x40

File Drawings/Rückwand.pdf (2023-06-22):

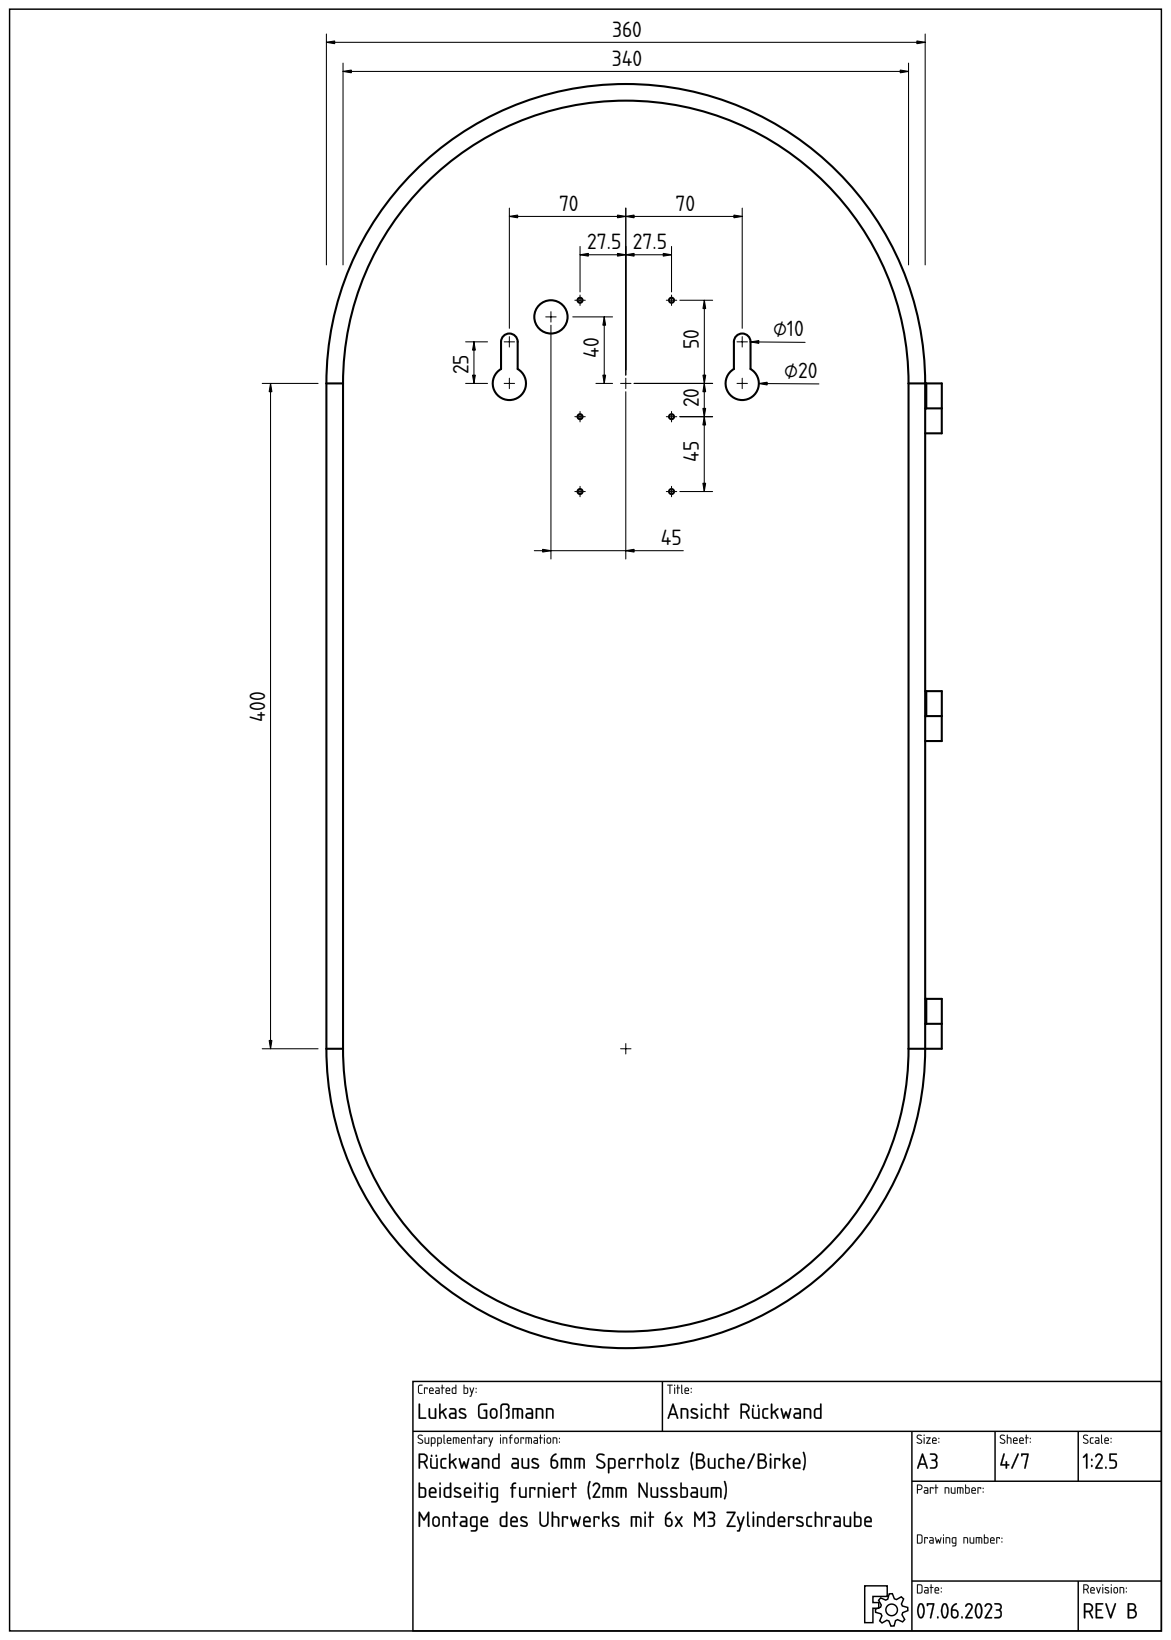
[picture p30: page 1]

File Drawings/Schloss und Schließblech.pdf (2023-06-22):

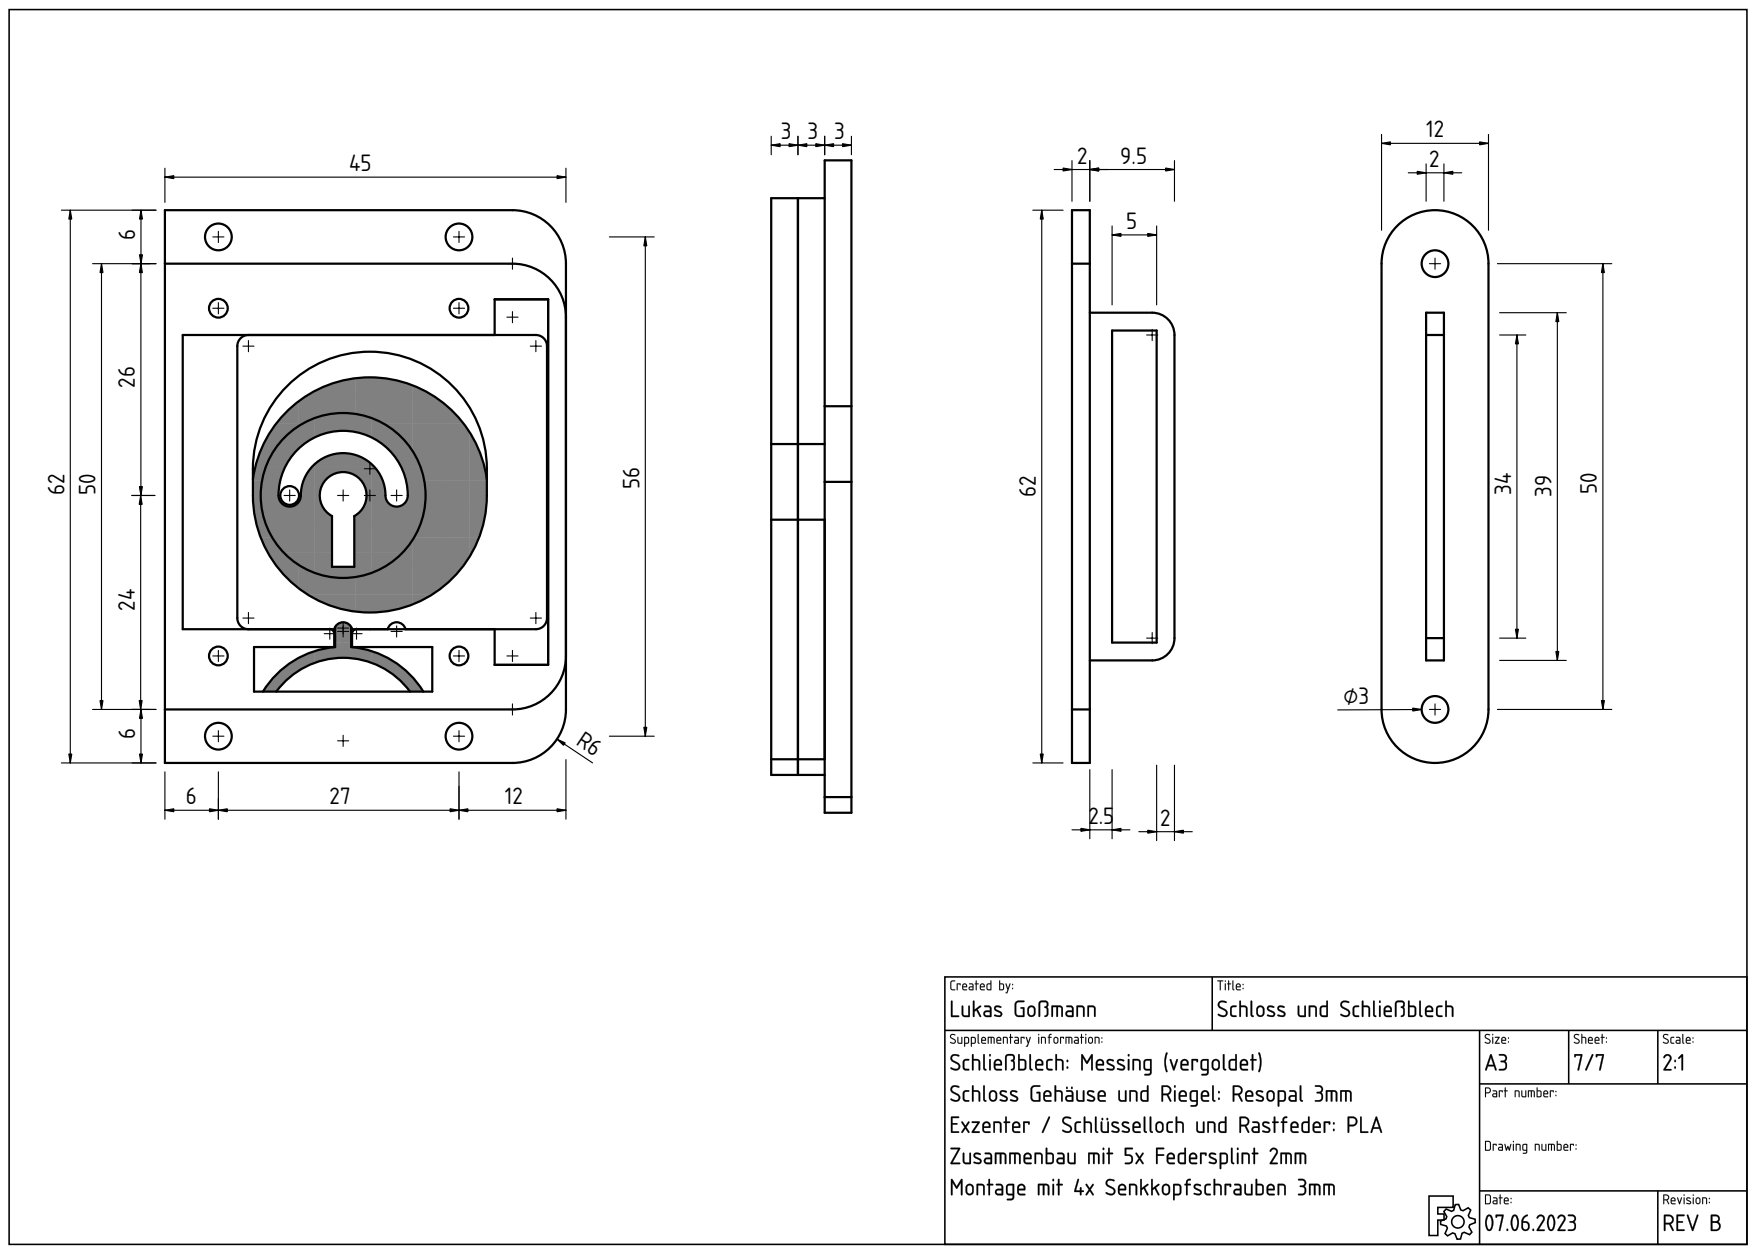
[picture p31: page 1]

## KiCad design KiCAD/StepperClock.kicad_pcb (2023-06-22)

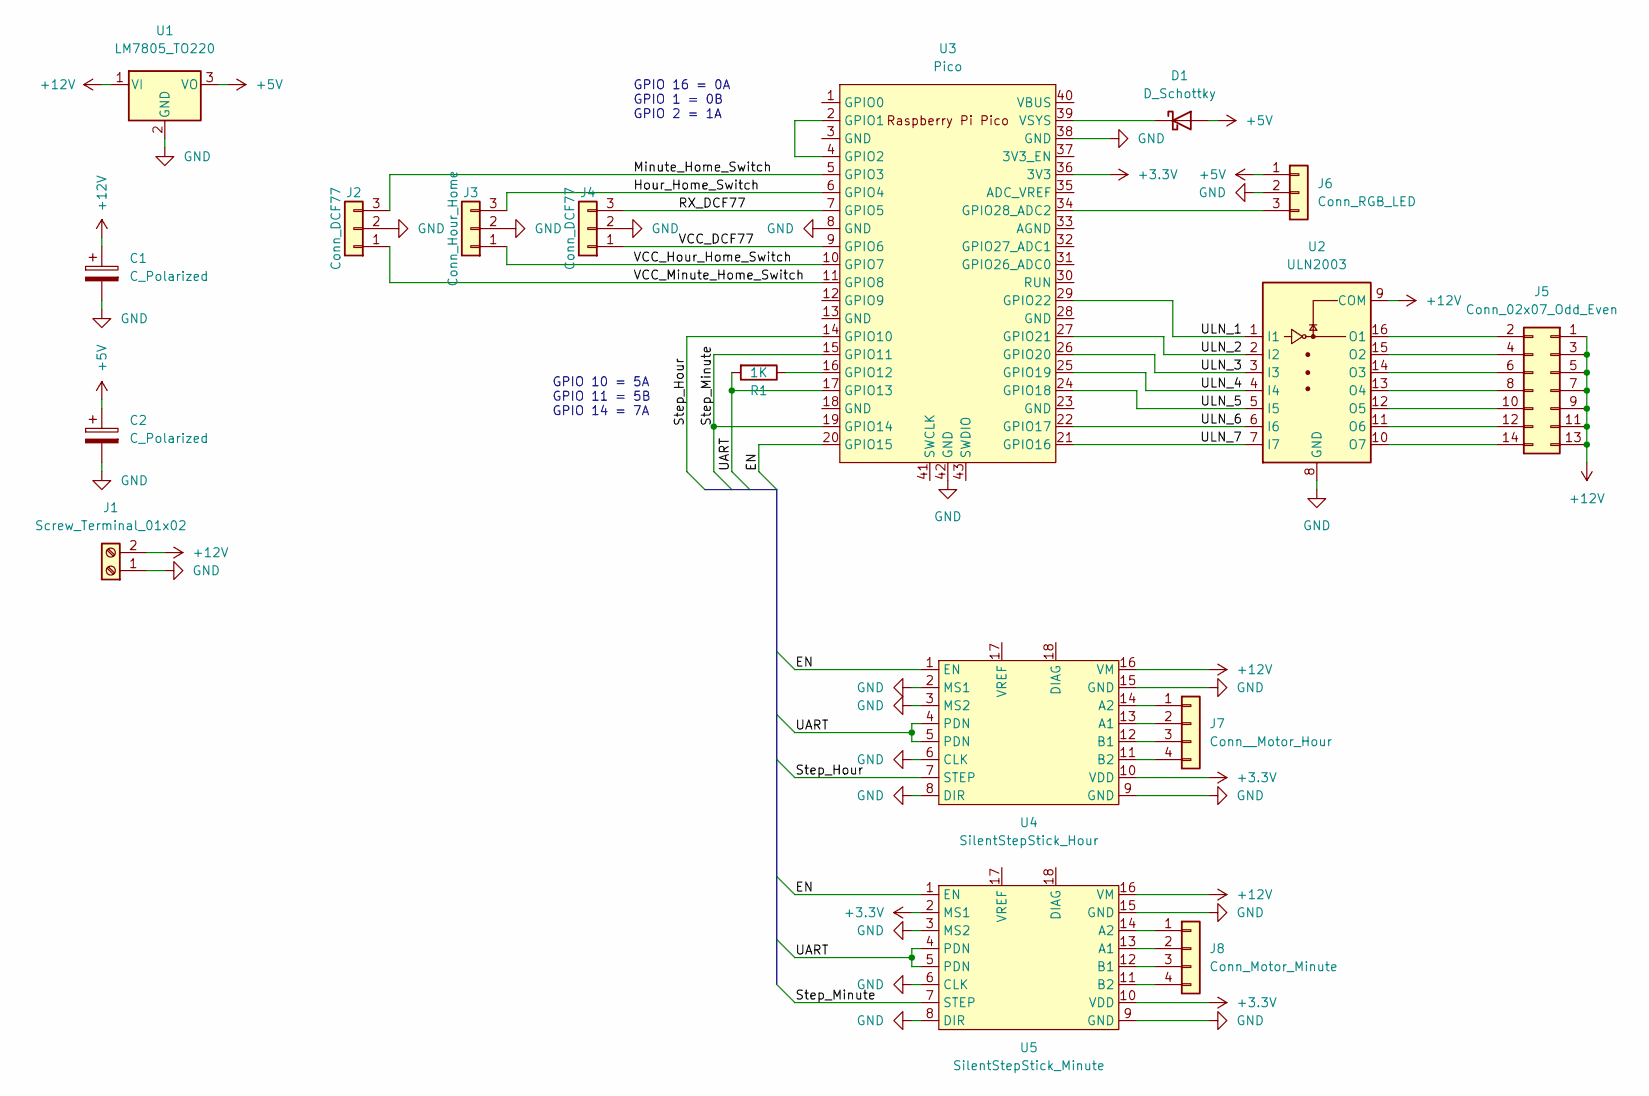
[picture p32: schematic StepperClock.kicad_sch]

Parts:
C1, C2: C_Polarized; CP_Radial_D10.0mm_P5.00mm_P7.50mm
D1: D_Schottky; D_DO-15_P10.16mm_Horizontal
J1: Screw_Terminal_01x02; TerminalBlock_RND_205-00232_1x02_P5.08mm_Horizontal
J2, J4: Conn_DCF77; PinHeader_1x03_P2.54mm_Vertical
J3: Conn_Hour_Home; PinHeader_1x03_P2.54mm_Vertical
J5: Conn_02x07_Odd_Even; PinHeader_2x07_P2.54mm_Vertical
J6: Conn_RGB_LED; PinHeader_1x03_P2.54mm_Vertical
J7: Conn__Motor_Hour; PinHeader_1x04_P2.54mm_Vertical
J8: Conn_Motor_Minute; PinHeader_1x04_P2.54mm_Vertical
R1: 1K; R_Axial_DIN0207_L6.3mm_D2.5mm_P10.16mm_Horizontal
U1: LM7805_TO220; TO-220-3_Vertical
U2: ULN2003; SOIC-16_3.9x9.9mm_P1.27mm
U3: Pico; RPi_Pico_SMD_TH
U4: SilentStepStick_Hour; SilentStepStick
U5: SilentStepStick_Minute; SilentStepStick

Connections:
+3.3V: U3.36 (3V3), U4.10 (VDD), U5.2 (MS1), U5.10 (VDD)
+5V: C2.1, D1.2 (A), J6.1, U1.3 (VO)
+12V: C1.1, J1.2, J5.1, J5.3, J5.5, J5.7, J5.9, J5.11, J5.13, U1.1 (VI), U2.9 (COM), U4.16 (VM), U5.16 (VM)
/EN: U3.20 (GPIO15), U4.1 (EN), U5.1 (EN)
/Hour_Home_Switch: J3.3, U3.6 (GPIO4)
/Minute_Home_Switch: J2.3, U3.5 (GPIO3)
/RX_DCF77: J4.3, U3.7 (GPIO5)
/Step_Hour: U3.14 (GPIO10), U4.7 (STEP)
/Step_Minute: U3.15 (GPIO11), U3.19 (GPIO14), U5.7 (STEP)
/UART: R1.2, U3.17 (GPIO13), U4.4 (PDN), U4.5 (PDN), U5.4 (PDN), U5.5 (PDN)
/ULN_1: U2.1 (I1), U3.29 (GPIO22)
/ULN_2: U2.2 (I2), U3.27 (GPIO21)
/ULN_3: U2.3 (I3), U3.26 (GPIO20)
/ULN_4: U2.4 (I4), U3.25 (GPIO19)
/ULN_5: U2.5 (I5), U3.24 (GPIO18)
/ULN_6: U2.6 (I6), U3.22 (GPIO17)
/ULN_7: U2.7 (I7), U3.21 (GPIO16)
/VCC_DCF77: J4.1, U3.9 (GPIO6)
/VCC_Hour_Home_Switch: J3.1, U3.10 (GPIO7)
/VCC_Minute_Home_Switch: J2.1, U3.11 (GPIO8)
GND: C1.2, C2.2, J1.1, J2.2, J3.2, J4.2, J6.2, U1.2 (GND), U2.8 (GND), U3.8 (GND), U3.38 (GND), U3.42 (GND), U4.2 (MS1), U4.3 (MS2), U4.6 (CLK), U4.8 (DIR), U4.9 (GND), U4.15 (GND), U5.3 (MS2), U5.6 (CLK), U5.8 (DIR), U5.9 (GND), U5.15 (GND)
unnamed: D1.1 (K), U3.39 (VSYS)
unnamed: J5.2, U2.16 (O1)
unnamed: J5.4, U2.15 (O2)
unnamed: J5.6, U2.14 (O3)
unnamed: J5.8, U2.13 (O4)
unnamed: J5.10, U2.12 (O5)
unnamed: J5.12, U2.11 (O6)
unnamed: J5.14, U2.10 (O7)
unnamed: J6.3, U3.34 (GPIO28_ADC2)
unnamed: J7.1, U4.14 (A2)
unnamed: J7.2, U4.13 (A1)
unnamed: J7.3, U4.12 (B1)
unnamed: J7.4, U4.11 (B2)
unnamed: J8.1, U5.14 (A2)
unnamed: J8.2, U5.13 (A1)
unnamed: J8.3, U5.12 (B1)
unnamed: J8.4, U5.11 (B2)
unnamed: U3.2 (GPIO1), U3.4 (GPIO2)
unnamed: R1.1, U3.16 (GPIO12)

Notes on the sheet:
GPIO 16 = 0A GPIO 1 = 0B GPIO 2 = 1A
GPIO 10 = 5A GPIO 11 = 5B GPIO 14 = 7A

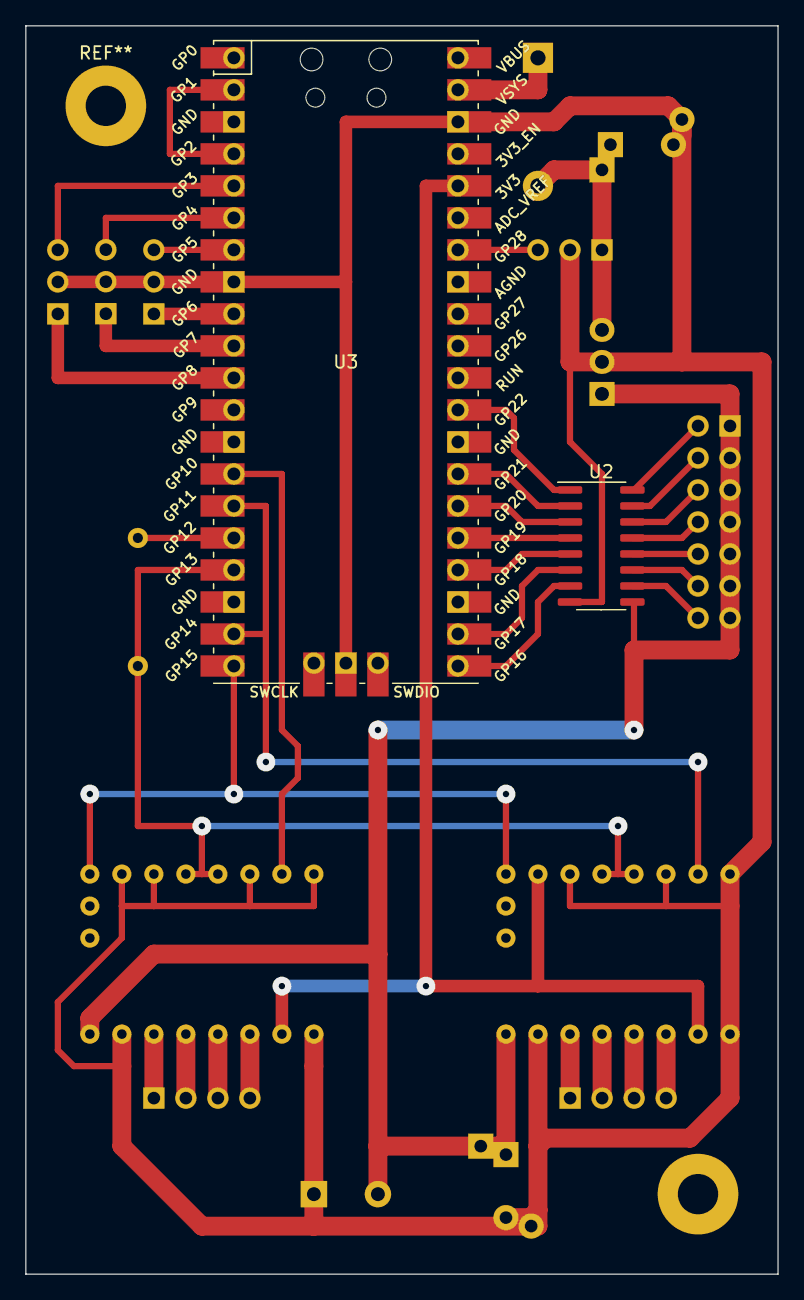
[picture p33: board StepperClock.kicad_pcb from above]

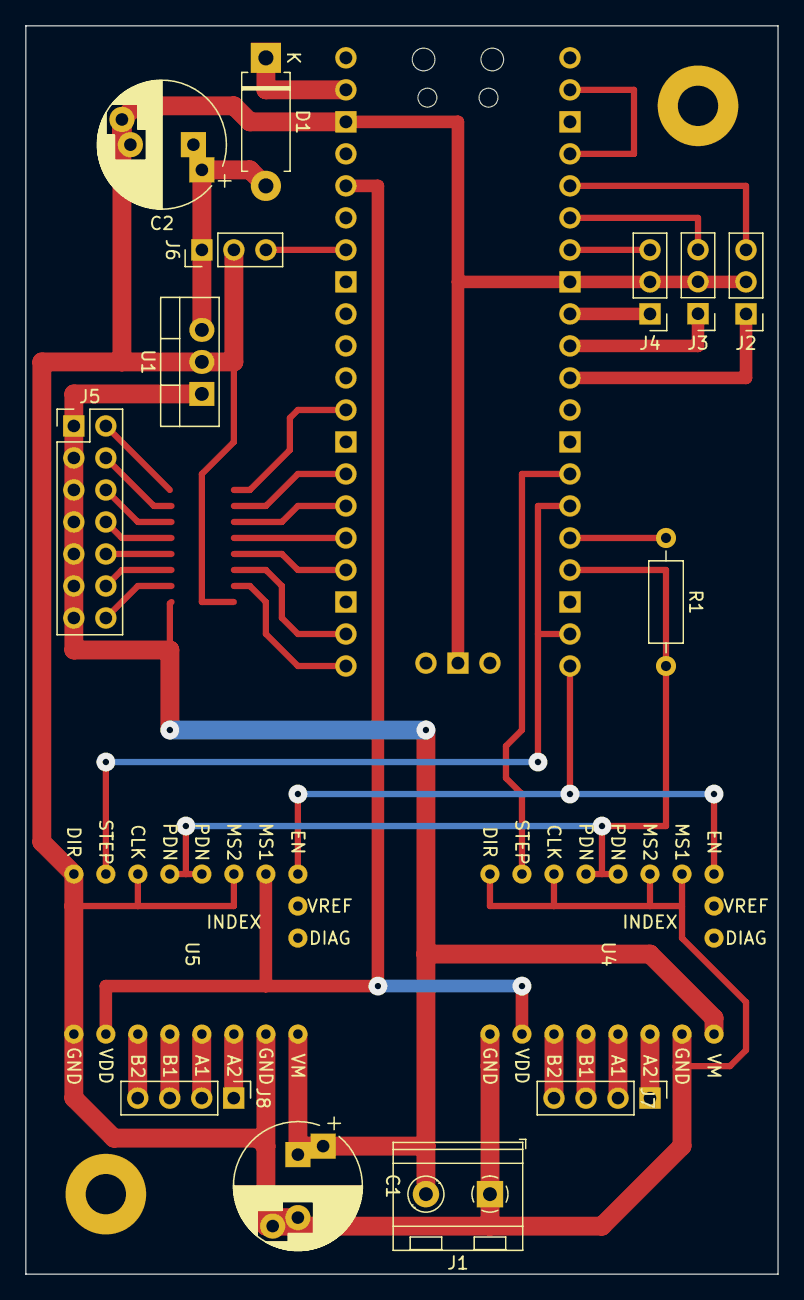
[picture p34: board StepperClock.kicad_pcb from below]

Board: 2 copper layers, 59.7 x 99.1 mm, 17 parts (15 on the bottom side), 40 nets.

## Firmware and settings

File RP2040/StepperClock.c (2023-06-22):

#include <stdio.h>

#include "pico/stdlib.h"
#include "pico/util/datetime.h"

// For scb_hw so we can enable deep sleep
#include "hardware/structs/scb.h"

// For __wfi() function
#include "hardware/sync.h"

#include "hardware/rtc.h"

#include "StepperClock_Config.h"
#include "StepperClock_PWM_STEPPER.h"
#include "StepperClock_PWM_PENDULUM.h"
#include "StepperClock_Trinamic.h"
#include "StepperClock_RTC.h"

// #if !PICO_NO_FLASH
// #error "This code must be built to run from SRAM!"
// #endif

/// @brief Handles the usb power detection gpio pin going high.
/// @param gpio The gpio pin that caused the interrupt.
/// @param event_mask The type of interrupt that occured
void usbPowerDetectionHandler(uint gpio, uint32_t event_mask)
{
    if (gpio == 24 && event_mask == GPIO_IRQ_EDGE_RISE)
    {
        // Show that we are awake
        gpio_put(25, true);

        // Disable IRQ for rising edge
        gpio_set_irq_enabled(24, GPIO_IRQ_EDGE_RISE, false);

        // Disable sleep on exit of IRQ hanlder
        scb_hw->scr &= ~M0PLUS_SCR_SLEEPONEXIT_BITS;
    }
}

/// @brief Puts the current core to sleep until gpio pin 24 (usb power detection) goes high.
void goToSleep()
{
    // Enable IRQ for rising edge of usb power
    gpio_set_irq_enabled_with_callback(24, GPIO_IRQ_EDGE_RISE, true, usbPowerDetectionHandler);

    // Turn off all clocks when in sleep mode except for RTC
    // TODO: Check which other clocks need to keep running
    // clocks_hw->sleep_en0 = CLOCKS_SLEEP_EN0_CLK_RTC_RTC_BITS;
    // clocks_hw->sleep_en1 = 0x0;

    // Show that we went to sleep
    gpio_put(25, false);

    // Enable sleep and automatic sleep on exit from irq handler
    scb_hw->scr |= (M0PLUS_SCR_SLEEPDEEP_BITS | M0PLUS_SCR_SLEEPONEXIT_BITS);

    // Go to sleep
    __wfi();
}

/// @brief Reads a line from stdin. Aborts when the virtual serial console gets disconnected.
/// @param buffer The buffer to write the data into.
/// @param sizeOfBuffer The size of the buffer.
/// @return Number of chars read or zero when serial console got disconnected.
uint32_t readLine(char *buffer, uint32_t sizeOfBuffer)
{
    uint32_t index = 0;

    bool powerConnected = false;
    while (powerConnected = gpio_get(24) && index < sizeOfBuffer)
    {
        int c = getchar_timeout_us(1000000); // 1s

        if (c == PICO_ERROR_TIMEOUT)
            continue;

        if (c == '\n' || c == '\r')
        {
            puts("");
            break;
        }

        // Only printable ascii
        if (c < ' ' || c > '~')
            continue;

        putchar_raw(c);
        buffer[index++] = c;
    }

    // If power got disconnected before receiving a complete line return zero
    if (!powerConnected)
        return 0;

    return index;
}

/// @brief Converts chars 0 to 9 to an integer.
/// @param c The char to convert.
/// @param number The result of the converion.
/// @return true when the character was between 0 to 9, otherwise false.
bool convertCharToNumber(char c, uint32_t *number)
{
    if (c >= '0' && c <= '9')
    {
        *number = c - '0';
        return true;
    }

    return false;
}

/// @brief Parses a datetime with the given format dd.mm.yy hh:mm
/// @param buffer The buffer containing the string to parse.
/// @param sizeofBuffer The size of the buffer.
/// @param datetime The parsed date time.
/// @return true when the date time was parsed successfully, otherwise false
bool parseDateTime(char *buffer, uint32_t sizeofBuffer, datetime_t *datetime)
{
    if (sizeofBuffer != 14)
    {
        printf("Invalid length: %d\n", sizeofBuffer);
        return false;
    }

    uint32_t digit = 0;
    // Day
    if (!convertCharToNumber(buffer[0], &digit))
    {
        printf("Invalid char (day digit 1): %c\n", buffer[0]);
        return false;
    }
    datetime->day = digit;

    if (!convertCharToNumber(buffer[1], &digit))
    {
        printf("Invalid char (day digit 2): %c\n", buffer[1]);
        return false;
    }
    datetime->day = ((datetime->day * 10) + digit);

    if (buffer[2] != '.')
    {
        printf("Invalid char (day month seperator): %c\n", buffer[2]);
        return false;
    }

    // Month
    if (!convertCharToNumber(buffer[3], &digit))
    {
        printf("Invalid char (month digit 1): %c\n", buffer[3]);
        return false;
    }
    datetime->month = digit;

    if (!convertCharToNumber(buffer[4], &digit))
    {
        printf("Invalid char (month digit 2): %c\n", buffer[4]);
        return false;
    }
    datetime->month = ((datetime->month * 10) + digit);

    if (buffer[5] != '.')
    {
        printf("Invalid char (month year seperator): %c\n", buffer[5]);
        return false;
    }

    // Year
    if (!convertCharToNumber(buffer[6], &digit))
    {
        printf("Invalid char (year digit 1): %c\n", buffer[6]);
        return false;
    }
    datetime->year = digit;

    if (!convertCharToNumber(buffer[7], &digit))
    {
        printf("Invalid char (year digit 2): %c\n", buffer[7]);
        return false;
    }
    datetime->year = (2000 + ((datetime->year * 10) + digit));

    if (buffer[8] != ' ')
    {
        printf("Invalid char (year hour seperator): %c\n", buffer[8]);
        return false;
    }

    // Hour
    if (!convertCharToNumber(buffer[9], &digit))
    {
        printf("Invalid char (hour digit 1): %c\n", buffer[9]);
        return false;
    }
    datetime->hour = digit;

    if (!convertCharToNumber(buffer[10], &digit))
    {
        printf("Invalid char (hour digit 2): %c\n", buffer[10]);
        return false;
    }
    datetime->hour = ((datetime->hour * 10) + digit);

    if (datetime->hour > 23)
    {
        printf("Hour out of range (0-23): %02d", datetime->hour);
        return false;
    }

    if (buffer[11] != ':')
    {
        printf("Invalid char (hour minute seperator): %c\n", buffer[11]);
        return false;
    }

    // Minute
    if (!convertCharToNumber(buffer[12], &digit))
    {
        printf("Invalid char (minute digit 1): %c\n", buffer[12]);
        return false;
    }
    datetime->min = digit;

    if (!convertCharToNumber(buffer[13], &digit))
    {
        printf("Invalid char (minute digit 2): %c\n", buffer[12]);
        return false;
    }
    datetime->min = ((datetime->min * 10) + digit);

    if (datetime->min > 59)
    {
        printf("Minute out of range (0-59): %02d", datetime->min);
        return false;
    }

    datetime->sec = 0;
    datetime->dotw = 0;

    return true;
}

int main()
{
    // Wait 500ms before trying to init anything
    sleep_ms(500);

    configureTrinamicDrivers(TMC_UART, TMC_ENABLE_PIN, TMC_UART_TX_PIN, TMC_UART_RX_PIN);
    pendulumInit(PENDULUM_FREQUENCY, PENDULUM_PULSE_DURATION, true);
    datetime_t dateAndTime = {
        .year = 2023,
        .month = 05,
        .day = 10,
        .dotw = 0, // 0 is Sunday, so 5 is Friday
        .hour = 12,
        .min = 00,
        .sec = 00,
    };
    rtcInit(&dateAndTime);
    homeAndSeekClockHands();
    configurePwmForNormalOperation();

    // USB power detection gpio
    gpio_init(24);
    gpio_set_dir(24, false);

    // Onboard led
    gpio_init(25);
    gpio_set_dir(25, true);
    gpio_put(25, true);

    // If usb power isnt connected to to sleep
    if (!gpio_get(24))
        goToSleep();

    // Either we awoke from sleep or power was connected already
    while (true)
    {
        // Show that we are awake
        gpio_put(25, true);

        // Wait 500ms before attempting to do anything
        sleep_ms(500);

        if (CLOCK_RESTART_TRIGGER)
        {
            // Only trigger this once (when waking up)
            CLOCK_RESTART_TRIGGER = false;

            // Homing needs to be performed outisde of an IRQ handler since the homing process uses IRQs
            homeAndSeekClockHands();
            configurePwmForNormalOperation();

            // After homing is done jump to the end of the loop (which makes the pico go back to sleep)
            goto endOfLoop;
        }

        // While power is connected to the usb port try to init stdio through usb
        bool powerConnected = false;
        while (powerConnected = gpio_get(24))
        {
            if (stdio_usb_init())
                break;

            sleep_ms(1000);
        }
        if (!powerConnected)
            goto endOfLoop;

        // Wait until something has connected to the virtual serial port
        while (powerConnected = gpio_get(24))
        {
            if (stdio_usb_connected())
                break;

            sleep_ms(1000);
        }
        if (!powerConnected)
            goto endOfLoop;

        // Stay in the "set time" loop until power is disconnected
        while (gpio_get(24))
        {
            // Display start message
            puts("StepperClock V1.0 (Release)");
            rtc_get_datetime(&dateAndTime);
            printf("Current date and time: %02d.%02d.%d %02d:%02d\n",
                   dateAndTime.day,
                   dateAndTime.month,
                   dateAndTime.year,
                   dateAndTime.hour,
                   dateAndTime.min);
            puts("Press enter to continue.");

            // Wait until enter is pressed
            while (powerConnected = gpio_get(24))
            {
                int c = getchar_timeout_us(1000000); // 1s

                if (c == PICO_ERROR_TIMEOUT)
                    continue;

                if (c == '\n' || c == '\r')
                    break;
            }
            if (!powerConnected)
                goto endOfLoop;

            char buffer[128];

            // Display prompt for setting the date and time
            puts("Type date and time (dd.mm.yy hh:mm) and press enter.");
            while (powerConnected = gpio_get(24))
            {
                uint32_t numberOfCharsRead = readLine(buffer, count_of(buffer));

                // If nothing has been read either the power has been disconnected or enter was pressed immediately
                if (numberOfCharsRead == 0)
                    continue;

                bool success = parseDateTime(buffer, numberOfCharsRead, &dateAndTime);
                if (success)
                {
                    printf("Got date and time: %02d.%02d.%d %02d:%02d\n",
                           dateAndTime.day,
                           dateAndTime.month,
                           dateAndTime.year,
                           dateAndTime.hour,
                           dateAndTime.min);
                    break;
                }

                puts("Invalid input!");
            }
            if (!powerConnected)
                goto endOfLoop;

            rtcInit(&dateAndTime);
            homeAndSeekClockHands();
            configurePwmForNormalOperation();

            puts("Time set successfully!");
            sleep_ms(500);
        }

    endOfLoop:
        goToSleep();
    }

    return 0;
}

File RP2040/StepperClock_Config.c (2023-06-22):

#include "StepperClock_Config.h"

const uint8_t CLOCK_SLEEP_MODE_HOUR = 23;
const uint8_t CLOCK_WAKE_UP_HOUR = 05;

// Offsets are in seconds to the 12 o'clock position
// Example:
// After homing the minute hands points at 45 minutes and 30 seconds
// This means there are 14 minutes and 30 seconds left for it to reach the 12 o'clock position.
// The value for the offset is calculated as follows:
// 14 * 60 + 30 = 870
// The same thing applies to the hour hand (just pretend its the minute hand for calculating the offset)
const uint32_t HOME_POSITION_OFFSET_MINUTE = (46 * 60) + 27;
const uint32_t HOME_POSITION_OFFSET_HOUR = (11 * 60) + 30;

const uint32_t HOUR_HOME_PIN = 4;
const uint32_t HOUR_HOME_POWER_PIN = 7;
const uint32_t HOUR_PULSE_PIN = 10;
const uint32_t HOUR_PULSE_IN_PIN = 11;
const uint8_t TMC_HOUR_SLAVE_ADDRESS = 0;

const uint32_t MINUTE_HOME_PIN = 3;
const uint32_t MINUTE_HOME_POWER_PIN = 8;
const uint32_t MINUTE_PULSE_PIN = 14;
const uint8_t TMC_MINUTE_SLAVE_ADDRESS = 1;

const uint32_t PENDULUM_PULSE_PIN = 16;
const uint32_t PENDULUM_PULSE_IN_PIN = 1;
const uint32_t PENDULUM_BASE_PULSE_PIN = 2;

// Pendulum length of 350mm
const double PENDULUM_FREQUENCY = 0.8425;     // Hz
const double PENDULUM_PULSE_DURATION = 160.0; // ms

// Other ULN pins = 17, 18, 19, 20, 21, 22

uart_inst_t *TMC_UART = uart0;
const uint32_t TMC_ENABLE_PIN = 15;
const uint32_t TMC_UART_TX_PIN = 12;
const uint32_t TMC_UART_RX_PIN = 13;

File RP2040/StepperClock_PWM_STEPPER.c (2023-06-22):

#include <math.h>

#include "StepperClock_Config.h"

#include "hardware/pwm.h"
#include "hardware/gpio.h"
#include "hardware/rtc.h"

#include "StepperClock_PWM_STEPPER.h"

uint32_t map(uint32_t x, uint32_t in_min, uint32_t in_max, uint32_t out_min, uint32_t out_max)
{
    float x_float = (float)x;
    float in_min_float = (float)in_min;
    float in_max_float = (float)in_max;
    float out_min_float = (float)out_min;
    float out_max_float = (float)out_max;
    float result = (x_float - in_min_float) * (out_max_float - out_min_float) / (in_max_float - in_min_float) + out_min_float;
    return (uint32_t)roundf(result);
}

void convertTimeToSteps(int8_t hour, int8_t min, int8_t sec, uint32_t *stepsToNewHourPosition, uint32_t *stepsToNewMinutePosition)
{
    // Step counts are based on both hands being at 12 o'clock position
    // Each stepper has to move 51200 steps per revolution (200 fullsteps * 256 microsteps)
    const uint32_t stepsPerRevolution = 200 * 256;
    const uint32_t stepsPer5Minutes = stepsPerRevolution / 12;
    const uint32_t stepsPerSecond = stepsPerRevolution / 60 / 60;

    // Position for hour hands is calculated from current hour + and offset for the amout of minutes that already passed in that hour
    uint32_t hourLimitedTo12HourTime = hour % 12;
    *stepsToNewHourPosition = map(hourLimitedTo12HourTime, 0, 12, 0, stepsPerRevolution) + map(min, 0, 60, 0, stepsPer5Minutes);

    // Position for minute hands is calculated from current minute + an offset for the amount of seconds in that minute that already passed
    *stepsToNewMinutePosition = map(min, 0, 60, 0, stepsPerRevolution) + map(sec, 0, 60, 0, stepsPerSecond);
}

uint32_t configurePwmForHomeAndSeek(uint32_t pin, irq_handler_t pwmWrapIrqHandler)
{
    /// Setup gpio and pwm
    assert(pwm_gpio_to_channel(pin) == PWM_CHAN_A);

    gpio_set_outover(pin, IO_BANK0_GPIO0_CTRL_OUTOVER_VALUE_NORMAL);

    gpio_init(pin);
    gpio_set_dir(pin, true);
    gpio_set_function(pin, GPIO_FUNC_PWM);
    const uint32_t slice_num = pwm_gpio_to_slice_num(pin);

    // Configure for 10khz
    pwm_config pwmConfig = pwm_get_default_config();
    pwm_config_set_clkdiv_int_frac(&pwmConfig, 1, 0);
    pwm_config_set_wrap(&pwmConfig, 12499);
    pwm_config_set_output_polarity(&pwmConfig, true, false);

    pwm_init(slice_num, &pwmConfig, false);
    pwm_set_chan_level(slice_num, PWM_CHAN_A, 12499 - 250);

    // Global irq setup
    irq_set_exclusive_handler(PWM_IRQ_WRAP, pwmWrapIrqHandler);

    pwm_clear_irq(slice_num);
    pwm_set_irq_enabled(slice_num, true);
    irq_set_enabled(PWM_IRQ_WRAP, true);

    return slice_num;
}

void deconfigurePwmFromHomeAndSeek(uint32_t pin, irq_handler_t pwmWrapIrqHandler)
{
    uint32_t slice_num = pwm_gpio_to_slice_num(pin);

    // Global irq setup
    pwm_set_enabled(slice_num, false);
    irq_set_enabled(PWM_IRQ_WRAP, false);
    pwm_set_irq_enabled(slice_num, false);

    // Only remove handler if one exists otherwise it might crash
    if (irq_get_exclusive_handler(PWM_IRQ_WRAP) != NULL)
        irq_remove_handler(PWM_IRQ_WRAP, pwmWrapIrqHandler);

    pwm_clear_irq(slice_num);
}

void configurePwmForNormalOperation()
{
    gpio_set_outover(MINUTE_PULSE_PIN, IO_BANK0_GPIO0_CTRL_OUTOVER_VALUE_NORMAL);
    gpio_set_outover(HOUR_PULSE_PIN, IO_BANK0_GPIO0_CTRL_OUTOVER_VALUE_NORMAL);

    /// Setup pwm for minute hand
    gpio_init(MINUTE_PULSE_PIN);
    gpio_set_dir(MINUTE_PULSE_PIN, true);
    gpio_set_function(MINUTE_PULSE_PIN, GPIO_FUNC_PWM);
    const uint32_t slice_num_minute = pwm_gpio_to_slice_num(MINUTE_PULSE_PIN);

    // Configure for 14.22222222222222222hz
    pwm_config pwmConfigMinute = pwm_get_default_config();
    pwm_config_set_clkdiv_int_frac(&pwmConfigMinute, 140, 10);
    pwm_config_set_wrap(&pwmConfigMinute, 62499);

    pwm_init(slice_num_minute, &pwmConfigMinute, false);
    pwm_set_chan_level(slice_num_minute, PWM_CHAN_A, 2);

    // Setup pwm for hour hand
    gpio_init(HOUR_PULSE_PIN);
    gpio_set_dir(HOUR_PULSE_PIN, true);
    gpio_set_function(HOUR_PULSE_PIN, GPIO_FUNC_PWM);
    const uint32_t slice_num_hour = pwm_gpio_to_slice_num(HOUR_PULSE_PIN);
    assert(pwm_gpio_to_channel(HOUR_PULSE_PIN) == PWM_CHAN_A);

    gpio_init(HOUR_PULSE_IN_PIN);
    gpio_set_dir(HOUR_PULSE_IN_PIN, false);
    gpio_set_function(HOUR_PULSE_IN_PIN, GPIO_FUNC_PWM);
    const uint32_t slice_num_hour_in_pin = pwm_gpio_to_slice_num(HOUR_PULSE_IN_PIN);
    assert(slice_num_hour == slice_num_hour_in_pin);
    assert(pwm_gpio_to_channel(HOUR_PULSE_IN_PIN) == PWM_CHAN_B);

    // Configure for counting up to 12
    pwm_config pwmConfigHour = pwm_get_default_config();
    pwm_config_set_clkdiv_mode(&pwmConfigHour, PWM_DIV_B_RISING);
    pwm_config_set_clkdiv_int_frac(&pwmConfigHour, 1, 0);
    pwm_config_set_wrap(&pwmConfigHour, 11);

    pwm_init(slice_num_hour, &pwmConfigHour, false);
    pwm_set_chan_level(slice_num_hour, PWM_CHAN_A, 1);

    // Mask enable so the pwm blocks run in sync
    const uint32_t hourMask = (1 << slice_num_hour);
    const uint32_t minuteMask = (1 << slice_num_minute);
    const uint32_t mask = hourMask | minuteMask;
    hw_set_bits(&pwm_hw->en, mask);
}

void stopNormalOperation()
{
    const uint32_t slice_num_minute = pwm_gpio_to_slice_num(MINUTE_PULSE_PIN);
    const uint32_t slice_num_hour = pwm_gpio_to_slice_num(HOUR_PULSE_PIN);
    const uint32_t hourMask = (1 << slice_num_hour);
    const uint32_t minuteMask = (1 << slice_num_minute);
    const uint32_t mask = hourMask | minuteMask;
    hw_clear_bits(&pwm_hw->en, mask);

    pwm_set_counter(slice_num_minute, 0);
    pwm_set_counter(slice_num_hour, 0);

    // Force pins low as state after disable depends on the last value in the counter
    gpio_set_outover(MINUTE_PULSE_PIN, IO_BANK0_GPIO0_CTRL_OUTOVER_VALUE_LOW);
    gpio_set_outover(HOUR_PULSE_PIN, IO_BANK0_GPIO0_CTRL_OUTOVER_VALUE_LOW);
}
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

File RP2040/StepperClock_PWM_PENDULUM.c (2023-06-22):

#include <math.h>

#include "StepperClock_Config.h"
#include "StepperClock_PWM_PENDULUM.h"

#include "hardware/pwm.h"
#include "hardware/gpio.h"

void pendulumSetEnabled(bool enabled)
{
    const uint32_t slice_num_pendulum = pwm_gpio_to_slice_num(PENDULUM_PULSE_PIN);
    const uint32_t slice_num_pendulum_base = pwm_gpio_to_slice_num(PENDULUM_BASE_PULSE_PIN);

    if (enabled)
    {
        gpio_set_outover(PENDULUM_PULSE_PIN, IO_BANK0_GPIO0_CTRL_OUTOVER_VALUE_NORMAL);
        gpio_set_outover(PENDULUM_BASE_PULSE_PIN, IO_BANK0_GPIO0_CTRL_OUTOVER_VALUE_NORMAL);
    }
    else
    {
        pwm_set_counter(slice_num_pendulum, 0);
        pwm_set_counter(slice_num_pendulum_base, 0);

        // Force pins low as state after disable depends on the last value in the counter
        gpio_set_outover(PENDULUM_PULSE_PIN, IO_BANK0_GPIO0_CTRL_OUTOVER_VALUE_LOW);
        gpio_set_outover(PENDULUM_BASE_PULSE_PIN, IO_BANK0_GPIO0_CTRL_OUTOVER_VALUE_LOW);
    }

    // Enable dividing pwm unit first and clock generator pwm unit second
    pwm_set_enabled(slice_num_pendulum, enabled);
    pwm_set_enabled(slice_num_pendulum_base, enabled);
}

/// @brief Generates a signal with the given frequency and high duration
/// @param frequency The frequency in Hz with a resolution of 0.0001Hz
/// @param highDuration The high duration in ms with a resolution of 0.1ms (100us)
/// @param enabled True to enable the pendulum after init is done
void pendulumInit(double frequency, double highDuration, bool enabled)
{
    /// Setup pwm base
    gpio_init(PENDULUM_BASE_PULSE_PIN);
    gpio_set_dir(PENDULUM_BASE_PULSE_PIN, true);
    gpio_set_function(PENDULUM_BASE_PULSE_PIN, GPIO_FUNC_PWM);
    const uint32_t slice_num_pendulum_base = pwm_gpio_to_slice_num(PENDULUM_BASE_PULSE_PIN);

    // Configure for 1khz
    pwm_config pwmConfigPendulumBase = pwm_get_default_config();
    pwm_config_set_clkdiv_int_frac(&pwmConfigPendulumBase, 1, 0);
    pwm_config_set_wrap(&pwmConfigPendulumBase, 12499);

    pwm_init(slice_num_pendulum_base, &pwmConfigPendulumBase, false);
    pwm_set_chan_level(slice_num_pendulum_base, PWM_CHAN_A, 6250);

    // Setup pwm for division
    gpio_init(PENDULUM_PULSE_PIN);
    gpio_set_dir(PENDULUM_PULSE_PIN, true);
    gpio_set_function(PENDULUM_PULSE_PIN, GPIO_FUNC_PWM);
    const uint32_t slice_num_pendulum = pwm_gpio_to_slice_num(PENDULUM_PULSE_PIN);
    assert(pwm_gpio_to_channel(PENDULUM_PULSE_PIN) == PWM_CHAN_A);

    gpio_init(PENDULUM_PULSE_IN_PIN);
    gpio_set_dir(PENDULUM_PULSE_IN_PIN, false);
    gpio_set_function(PENDULUM_PULSE_IN_PIN, GPIO_FUNC_PWM);
    const uint32_t slice_num_pendulum_in_pin = pwm_gpio_to_slice_num(PENDULUM_PULSE_IN_PIN);
    assert(slice_num_pendulum == slice_num_pendulum_in_pin);
    assert(pwm_gpio_to_channel(PENDULUM_PULSE_IN_PIN) == PWM_CHAN_B);

    // Configure for counting up

    uint16_t wrap = (uint16_t)round(10000.0 / frequency);

    pwm_config pwmConfigPendulum = pwm_get_default_config();
    pwm_config_set_clkdiv_mode(&pwmConfigPendulum, PWM_DIV_B_RISING);
    pwm_config_set_clkdiv_int_frac(&pwmConfigPendulum, 1, 0);
    pwm_config_set_wrap(&pwmConfigPendulum, wrap);

    pwm_init(slice_num_pendulum, &pwmConfigPendulum, false);

    uint16_t chanLevel = (uint16_t)round(highDuration * 10);

    pwm_set_chan_level(slice_num_pendulum, PWM_CHAN_A, chanLevel);

    pendulumSetEnabled(enabled);
}

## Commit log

2023-06-22 Initial commit (removing history)
    [BendingFixture.FCStd, Case.FCStd, Clock.FCStd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]
2023-07-26 Made 3D models look nicer and updated readme with pictures
    [Clip.FCStd, Clock.FCStd, ClockFace.FCStd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]
2023-11-11 Long overdue updates
    [StepperClock.kicad_sch]
